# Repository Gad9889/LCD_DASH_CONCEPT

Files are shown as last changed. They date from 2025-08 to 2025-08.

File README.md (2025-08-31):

# Dash Concept – Design Summary (Rev 0.1)

A compact STM32H745-based dash concept for an LCD‑driven vehicle interface. This repository documents the hardware concept, interfaces, and bring‑up notes for the first spin (Rev 0.1).

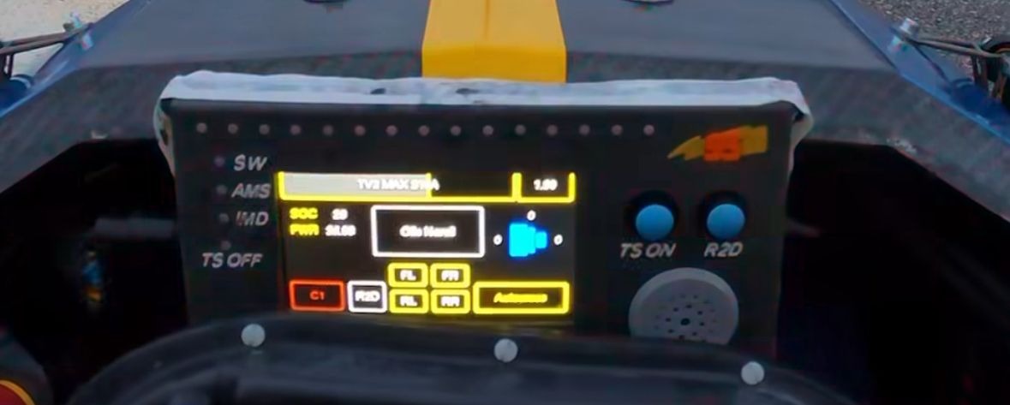
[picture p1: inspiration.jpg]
Inspiration – Chalmers Formula Student dashboard


> **Inspiration**: UI/UX styling reference from the Chalmers Formula Student team. The image is a visual reference, not a functional specification.

---

## Documents (in this repo)

Direct links with short descriptions:

- **Dash Concept Summary** → [Dash_Concept_Summary_Rev0_1.pdf](./Dash_Concept_Summary_Rev0_1.pdf) — condensed overview of the concept (Rev 0.1), interfaces, LCD details, RF notes, and expansion paths.
- **Schematics** → [Schematics.pdf](./Schematics.pdf) — electrical design: power (12 V → 3.3 V buck and decoupling), MCU pinout, FMC LCD connector, ST‑LINK/JTAG, CAN/USART, and RF (CC2500 with 26 MHz crystal and matching network).
- **Design Breakdown** → [Design Breakdown.pdf](./Design%20Breakdown.pdf) — manufacturing‑oriented summary: board dimensions, 4‑layer stackup with target impedances, layer previews (Top/Bottom/L1–L4), BOM snapshot, and drill table.
- **CubeMX Report** → [DashCubeMX.pdf](./DashCubeMX.pdf) — STM32CubeMX configuration: MCU selection and package, pin assignments (FMC NE3/A8, USART6, SPI1, FDCAN1), clock tree, and initial FMC timings.

---

## Highlights

- **Concept status**: Rev 0.1 (pre‑prototype)
- **MCU**: STM32H745ZITx (LQFP144), Cortex‑M7 + Cortex‑M4
- **Primary functions**: LCD over FMC, RF over SPI1 (CC2500), CAN‑FD, SWD/JTAG, UART console
- **Board**: 137 mm × 94 mm, 4‑layer FR‑4, target impedances 50 Ω SE / 90 Ω diff

## Hardware Overview

- **Power**: +12 V input → TPS62130 buck → +3.3 V. Local 100 nF decoupling per VDD plus bulk caps (e.g., 4.7 µF/10 µF/22 µF).
- **Clocks**: HSE bypass to PLL; targets M7 @ 480 MHz and M4 @ 240 MHz.

### Key Interfaces

| Interface | Details |
| --- | --- |
| **FMC (LCD)** | Bank1 **NE3** as chip‑select; **A8** used as D/C (register select). 16‑bit data bus **D0..D15**. Control **NOE=RD**, **NWE=WR**. |
| **USART6** | 115200 baud (TX PC6, RX PC7). |
| **SPI1** | NSS PA4, SCK PA5, MISO PA6, MOSI PA7 (to RF). |
| **FDCAN1** | FD mode (PB8 RX, PB9 TX). |
| **SWD/JTAG**  | ST‑LINK V3: SWDIO, SWCLK, JTDI, SWO, NRST. |

### LCD Screen Details — ER‑TFTM050‑5

| Parameter | Value |
| --- | --- |
| Diagonal size  | 5.0″ |
| Resolution | 800 × 480 (RGB) |
| Active area | 108.0 mm × 64.8 mm |
| Outline (PCB)  | 132.7 mm × 75.95 mm |
| Interface | 8080/6800 parallel, selectable 8/9/16/18/24‑bit; **SSD1963** controller |
| Supply options | VDD 3.3 V (J8 short) or 5.0 V (J8 open); logic VDDIO 3.3 V |
| Module current | ≈ 280 mA @ 5 V, up to ~450 mA @ 3.3 V |
| Brightness | 300 cd/m² (typ.) |
| Contrast | 500:1 (typ.) |
| Viewing angle  | L/R 75°, Up 75°, Down 60° (typ.) |
| Operating temp | −20 °C … +70 °C |

### LCD Connector (JP2 / CON1 highlights)

| Pin(s) | Signal | Notes |
| --- | --- | --- |
| 1, 40  | VSS | Ground |
| 2 | VDD | 3.3 V or 5 V (per module option) |
| 3 | /CS | Chip‑select — connect to **FMC NE3** |
| 4 | D/C | Data/Command — connect to **A8** |
| 5 | RD | 8080 read strobe — connect to **NOE**  |
| 6 | WR | 8080 write strobe — connect to **NWE** |
| 7 | RESET | Active‑low reset (recommended) |
| 8 | TE | Tearing effect (optional) |
| 9–32 | DB0–DB23 | Use **DB0–DB15** for 16‑bit mode |
| 39 | BL_ON | Backlight control (optional PWM) |

### RF Subsystem

- **Transceiver**: TI **CC2500** (2.4 GHz) on SPI1 with GDO0/GDO2 interrupts and a 26 MHz crystal.
- **Front‑end**: Minimal matching network and antenna port in Rev 0.1 (no PA/LNA/SAW). Future spins can add PA/LNA and alternative radios using spare I/O.

### FMC Timing (initial)

- Address setup: 15 cycles
- Data setup: 255 cycles
- Bus turn‑around: 15 cycles  
  _Tune per LCD controller timing requirements._

## Minimal Concept & Expansion Paths

Rev 0.1 targets power‑up, clocks, debug, FMC LCD, SPI RF, CAN, and UART console. Reserved pins/area allow:

- External storage (QSPI/SD), audio codec, backlight driver with PWM dimming
- Additional sensors and buttons/encoders
- Extended RF front‑end (PA/LNA) or radio swap

## References

- ST RM0399 — STM32H745/755/747/757 Reference Manual  
  https://www.st.com/resource/en/reference_manual/rm0399-stm32h745755-and-stm32h747757-advanced-armbased-32bit-mcus-stmicroelectronics.pdf
- EastRising ER‑TFTM050‑5 TFT LCD Datasheet  
  https://www.buydisplay.com/download/manual/ER-TFTM050-5_Datasheet.pdf

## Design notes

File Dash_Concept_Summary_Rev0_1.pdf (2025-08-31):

### Dash Concept - Design Summary (Rev 0.1)

# Dash Concept - Design Summary

Scope: this document summarizes the current concept board based on the STM32H745 microcontroller. Hardware status is Rev 0.1 (pre-prototype). It consolidates information from the CubeMX configuration and the schematics.

## Inspiration

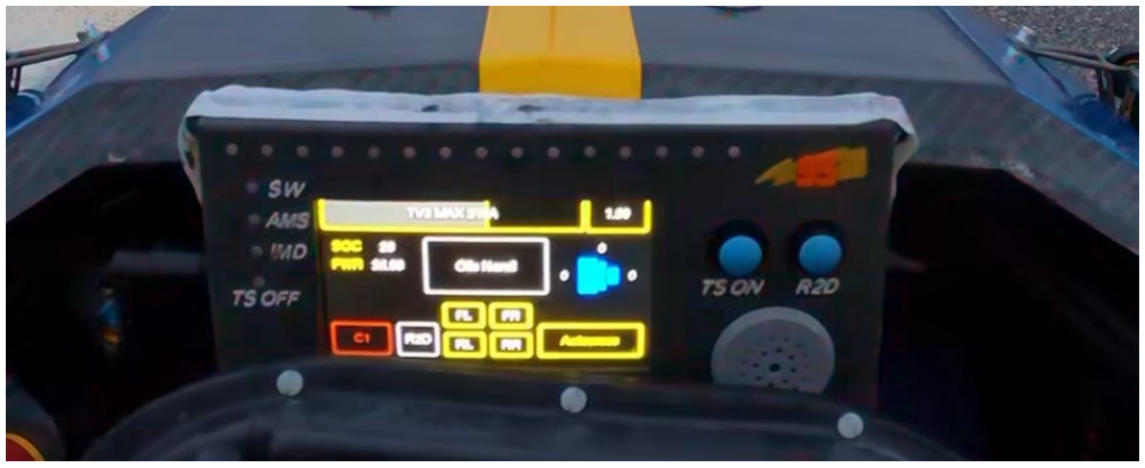
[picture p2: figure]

Dashboard visual inspiration: Chalmers Formula Student team. The image is used as a stylistic reference for UI layout and features, not as a functional specification.

## Board Overview

Form factor: 137 mm x 94 mm, thickness 1.6 mm, 4 layers (FR4). Target controlled impedances: 50 ohm single ended and 90 ohm differential per stackup. Primary functions: LCD via FMC, RF via SPI1, CAN FD via FDCAN1, debug via SWD/JTAG.

## MCU and Clocks

MCU: STM32H745ZITx (LQFP144), dual core Cortex-M7 and Cortex-M4. CubeMX configuration targets M7 at 480 MHz and M4 at 240 MHz using HSE bypass and PLLs.

## Power System

Input: +12 V. Main regulator: TPS62130 buck converter to +3.3 V. Local decoupling: 100 nF at each VDD/VSSA pin plus bulk values (for example 4.7 uF, 10 uF, 22 uF) as shown in the schematic.

## Key Interfaces

Interface | Details
FMC (LCD) | Bank1 NE3 as chip select. A8 used as D/C (register select). 16-bit data bus D0..D15. Control NOE=RD, NWE=WR.
USART6 | Async 115200 baud (TX on PC6, RX on PC7).
SPI1 | Master interface to RF transceiver (NSS PA4, SCK PA5, MISO PA6, MOSI PA7).
FDCAN1 | FD mode (PB8 RX, PB9 TX).
SWD/JTAG | ST-LINK V3: SWDIO, SWCLK, JTDI, SWO and NRST.

## RF Subsystem

2.4 GHz transceiver: CC2500 on SPI1 with GDO0/GDO2 interrupts and a 26 MHz crystal. Includes a compact matching network and antenna port. Rev 0.1 keeps the RF minimal for bring-up (no external PA/LNA or SAW). Future expansion can add PA/LNA front-end, on-board antenna options, or alternative radios using spare MCU I/O and board area.

## Initial FMC Timing (from CubeMX)

Address setup: 15 cycles; Data setup: 255 cycles; Bus turn around: 15 cycles. Adjust these values to meet the LCD controller timing.

## LCD Connector (ER-TFTM050-5, JP2/CON1 highlights)

Pin(s) | Signal | Notes
1,40 | VSS | Ground
2 | VDD | 3.3 V or 5 V (per module)
3 | /CS | Chip select (connect to FMC NE3)
4 | D/C | Data or Command (connect to A8)
5 | RD | 8080 read strobe (connect to NOE)
6 | WR | 8080 write strobe (connect to NWE)
7 | RESET | Active low, recommended
8 | TE | Optional tearing effect
9-32 | DB0-DB23 | Use DB0-DB15 for 16-bit mode
39 | BL_ON | Backlight control (optional PWM)

## LCD Screen Details (ER-TFTM050-5)

Parameter | Value
Diagonal size | 5.0 inch
Resolution | 800 x 480 (RGB)
Active area | 108.0 mm x 64.8 mm
Outline (PCB) | 132.7 mm x 75.95 mm
Interface | 8080/6800 parallel, selectable 8/9/16/18/24-bit; SSD1963 controller
Supply options | VDD 3.3 V (J8 short) or 5.0 V (J8 open); logic VDDIO 3.3 V
Module current (typ/max) | ~280 mA @5V, up to 450 mA @3.3V
Brightness (typ) | 300 cd/m²
Contrast (typ) | 500:1
Viewing angle (typ) | Left 75°, Right 75°, Up 75°, Down 60°
Operating temp | -20°C to +70°C

## Minimal Concept and Expansion Paths

Rev 0.1 focuses on the minimum viable hardware to validate power-up, clocks, debug, FMC LCD, SPI RF, CAN, and a UART console. The layout and spare pins leave room for future features such as external storage, audio codec, backlight driver with PWM dimming, additional sensors, and extended radio front-end.

## Files Provided

File | Description
Design Breakdown.pdf | Manufacturing-oriented summary: board dimensions, 4-layer stackup with target impedances, layer previews (Top/Bottom/L1–L4), BOM snapshot, and drill table.
Schematics.pdf | Electrical design: Power (12 V to 3.3 V buck and decoupling), I/O (MCU pinout, FMC LCD connector, ST-LINK/JTAG, CAN, USART), and RF (CC2500 with 26 MHz crystal, matching network, and antenna).
DashCubeMX.pdf | STM32CubeMX configuration report: MCU selection and package, pin assignments (FMC NE3/A8, USART6, SPI1, FDCAN1), clock tree, and initial FMC timings.

## References

MCU Reference Manual RM0399 (STM32H745/755/747/757): Open link (https://www.st.com/resource/en/reference_manual/rm0399-stm32h745755-and-stm32h747757-advanced-armbased-32bit-mcus-stmicroelectronics.pdf) (URL: https://www.st.com/resource/en/reference_manual/rm0399-stm32h745755-and-stm32h747757-advanced-armbased-32bit-mcus-stmicroelectronic s.pdf)

LCD Datasheet ER-TFTM050-5: Open link (https://www.buydisplay.com/download/manual/ER-TFTM050-5_Datasheet.pdf) (URL: https://www.buydisplay.com/download/manual/ER-TFTM050-5_Datasheet.pdf)

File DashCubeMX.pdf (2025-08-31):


31/08/2025

dash Project
Configuration Report

## 1. Description

### 1.1. Project

Project Name | dash
Board Name | custom
Generated with: | STM32CubeMX 6.14.0
Date | 08/31/2025

### 1.2. MCU

MCU Series | STM32H7
MCU Line | STM32H745/755
MCU name | STM32H745ZITx
MCU Package | LQFP144
MCU Pin number | 144

### 1.3. Core(s) information

Core(s) | ARM Cortex-M7 ARM Cortex-M4

## 2. Pinout Configuration

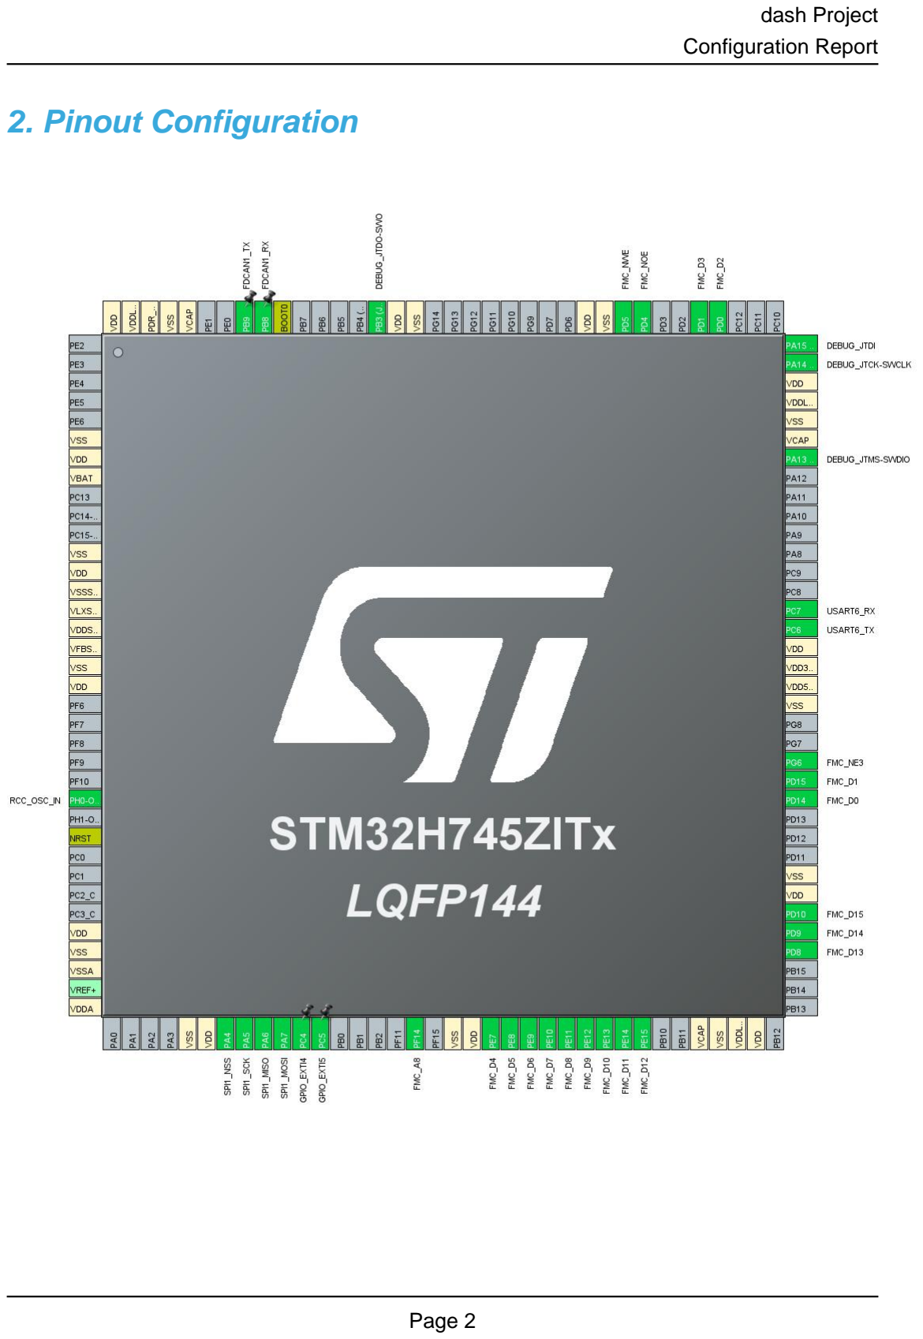
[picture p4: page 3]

## 3. Pins Configuration

Pin Number LQFP144 | Pin Name (function after reset) | Pin Type | Alternate Function(s) | Label
6 | VSS | Power
7 | VDD | Power
8 | VBAT | Power
12 | VSS | Power
13 | VDD | Power
14 | VSSSMPS | Power
15 | VLXSMPS | Power
16 | VDDSMPS | Power
17 | VFBSMPS | Power
18 | VSS | Power
19 | VDD | Power
25 | PH0-OSC_IN (PH0) | I/O | RCC_OSC_IN
27 | NRST | Reset
32 | VDD | Power
33 | VSS | Power
34 | VSSA | Power
36 | VDDA | Power
41 | VSS | Power
42 | VDD | Power
43 | PA4 | I/O | SPI1_NSS
44 | PA5 | I/O | SPI1_SCK
45 | PA6 | I/O | SPI1_MISO
46 | PA7 | I/O | SPI1_MOSI
47 | PC4 | I/O | GPIO_EXTI4
48 | PC5 | I/O | GPIO_EXTI5
53 | PF14 | I/O | FMC_A8
55 | VSS | Power
56 | VDD | Power
57 | PE7 | I/O | FMC_D4
58 | PE8 | I/O | FMC_D5
59 | PE9 | I/O | FMC_D6
60 | PE10 | I/O | FMC_D7
61 | PE11 | I/O | FMC_D8
62 | PE12 | I/O | FMC_D9
63 | PE13 | I/O | FMC_D10
64 | PE14 | I/O | FMC_D11

Pin Number LQFP144 | Pin Name (function after reset) | Pin Type | Alternate Function(s) | Label
65 | PE15 | I/O | FMC_D12
68 | VCAP | Power
69 | VSS | Power
70 | VDDLDO | Power
71 | VDD | Power
76 | PD8 | I/O | FMC_D13
77 | PD9 | I/O | FMC_D14
78 | PD10 | I/O | FMC_D15
79 | VDD | Power
80 | VSS | Power
84 | PD14 | I/O | FMC_D0
85 | PD15 | I/O | FMC_D1
86 | PG6 | I/O | FMC_NE3
89 | VSS | Power
90 | VDD50_USB | Power
91 | VDD33_USB | Power
92 | VDD | Power
93 | PC6 | I/O | USART6_TX
94 | PC7 | I/O | USART6_RX
102 | PA13 (JTMS/SWDIO) | I/O | DEBUG_JTMS-SWDIO
103 | VCAP | Power
104 | VSS | Power
105 | VDDLDO | Power
106 | VDD | Power
107 | PA14 (JTCK/SWCLK) | I/O | DEBUG_JTCK-SWCLK
108 | PA15 (JTDI) | I/O | DEBUG_JTDI
112 | PD0 | I/O | FMC_D2
113 | PD1 | I/O | FMC_D3
116 | PD4 | I/O | FMC_NOE
117 | PD5 | I/O | FMC_NWE
118 | VSS | Power
119 | VDD | Power
128 | VSS | Power
129 | VDD | Power
130 | PB3 (JTDO/TRACESWO) | I/O | DEBUG_JTDO-SWO
135 | BOOT0 | Boot
136 | PB8 | I/O | FDCAN1_RX
137 | PB9 | I/O | FDCAN1_TX
140 | VCAP | Power

Pin Number LQFP144 | Pin Name (function after reset) | Pin Type | Alternate Function(s) | Label
141 | VSS | Power
142 | PDR_ON | Power
143 | VDDLDO | Power
144 | VDD | Power

## 4. Clock Tree Configuration

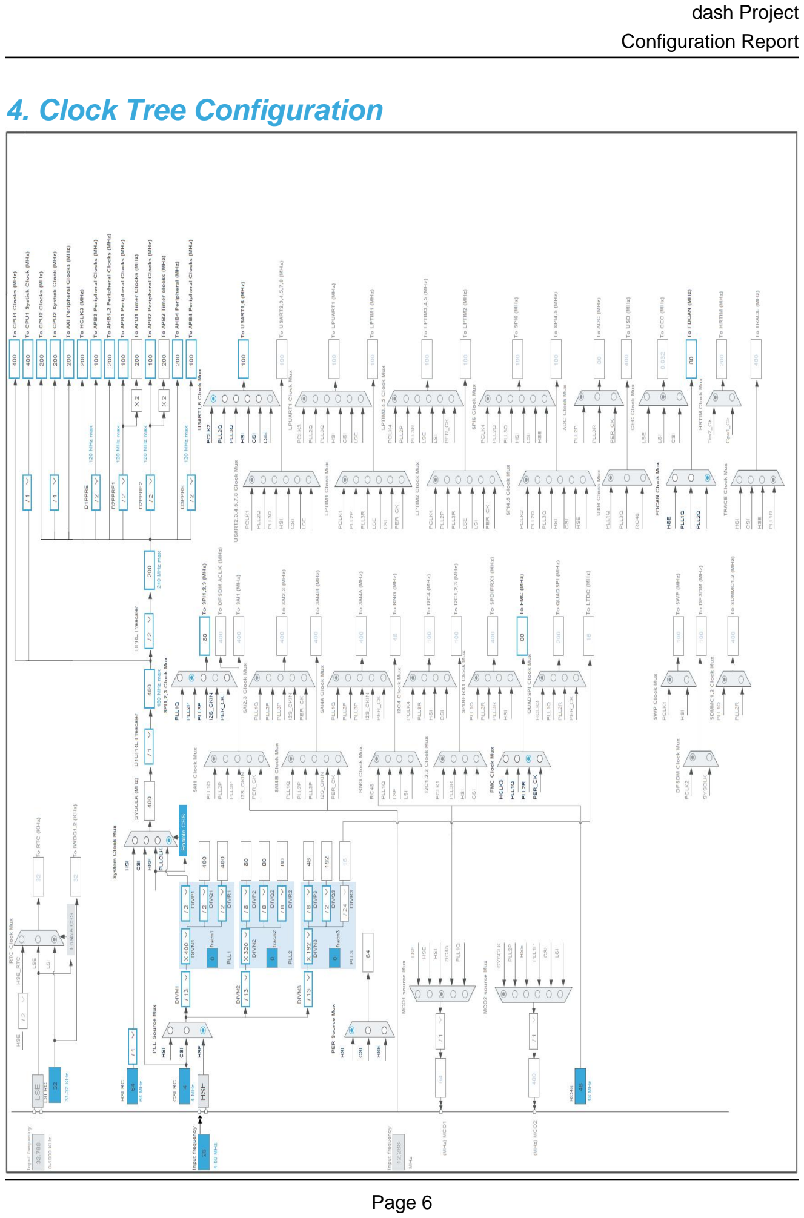
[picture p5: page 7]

## 1. Power Consumption Calculator report

### 1.1. Microcontroller Selection

Series | STM32H7
Line | STM32H745/755
MCU | STM32H745ZITx
Datasheet | DS12923_Rev1

### 1.2. Parameter Selection

Temperature | 25
Vdd | 3.0

### 1.3. Battery Selection

Battery | Li-SOCL2(DD36000)
Capacity | 36000.0 mAh
Self Discharge | 0.08 %/month
Nominal Voltage | 3.6 V
Max Cont Current | 450.0 mA
Max Pulse Current | 1000.0 mA
Cells in series | 1
Cells in parallel | 1

### 1.4. Sequence

Step | Step1 | Step2
Mode | RUN | STOP
Vdd | 3.0 | 3.0
Voltage Source | Battery | Battery
Range | VOS0: Scale0 | SVOS5: System-Scale5
D1 Mode | DRUN/CRUN | DSTANDBY
D2 Mode | DRUN/CRUN | DSTANDBY
D3 Mode | DRUN | DSTOP
Fetch Type | CM7: ITCM/Cache / CM4: FLASH_B/ART | CM7: NA / CM4: NA
CM7 Frequency | 480 MHz | 0 Hz
Clock Configuration | HSE BYP PLL ALL_IPs_ON | LSE Flash-ON
CM4 Frequency | 240 MHz | 0 Hz
Clock Source Frequency | 25 MHz | 0 Hz
Peripherals
Additional Cons. | 0 mA | 0 mA
Average Current | 247 mA | 145 µA
Duration | 0.1 ms | 0.9 ms
DMIPS | 1027.0 | 0.0
Category | In DS Table | In DS Table

### 1.5. Results

Sequence Time | 1 ms | Average Current | 24.83 mA
Battery Life | 1 month, 29 days, 21 hours | Average DMIPS | 1027.2001 DMIPS

### 1.6. Chart

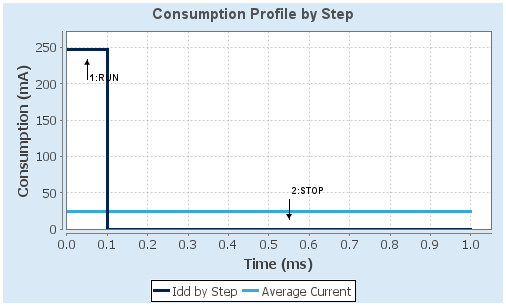
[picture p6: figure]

## 2. Software Project

### 2.1. Project Settings

Name | Value
Project Name | dash
Project Folder | C:\Users\ramga\Desktop\projects\dash
Toolchain / IDE | EWARM V8.50
Firmware Package Name and Version | STM32Cube FW_H7 V1.12.1
Application Structure | Advanced
Generate Under Root | No
Do not generate the main() | No
Minimum Heap Size | M4-0x200
Minimum Stack Size | M4-0x400

### 2.2. Code Generation Settings

Name | Value
STM32Cube MCU packages and embedded software | Copy all used libraries into the project folder
Generate peripheral initialization as a pair of '.c/.h' files | No
Backup previously generated files when re-generating | No
Keep User Code when re-generating | Yes
Delete previously generated files when not re-generated | Yes
Set all free pins as analog (to optimize the power consumption) | No
Enable Full Assert | No

### 2.3. Advanced Settings - Generated Function Calls ARM Cortex-M7

Rank | Function Name | Peripheral Instance Name
1 | SystemClock_Config | RCC
2 | MX_GPIO_Init | GPIO
3 | MX_CRC_Init | CRC
4 | MX_DMA2D_Init | DMA2D
5 | MX_FMC_Init | FMC

### 2.4. Advanced Settings - Generated Function Calls ARM Cortex-M4

Rank | Function Name | Peripheral Instance Name
1 | MX_GPIO_Init | GPIO

Rank | Function Name | Peripheral Instance Name
2 | MX_FDCAN1_Init | FDCAN1
3 | MX_SPI1_Init | SPI1
4 | MX_USART6_UART_Init | USART6

## 3. Peripherals and Middlewares Configuration

### 3.1. CORTEX_M4

3.1.1. Parameter Settings:

Core(s) Settings:

Context(s): | Cortex-M4
Initialized Context: | Cortex-M4
Power Domain: | D2

Cortex Memory Protection Unit Control Settings:
MPU Control Mode | Background Region Privileged accesses only + MPU Disabled during hard fault, NMI and FAULTMASK handlers *

Cortex Memory Protection Unit Region 0 Settings:

MPU Region | Disabled
Cortex Memory Protection Unit Region 1 Settings:
MPU Region | Disabled
Cortex Memory Protection Unit Region 2 Settings:
MPU Region | Disabled
Cortex Memory Protection Unit Region 3 Settings:
MPU Region | Disabled
Cortex Memory Protection Unit Region 4 Settings:
MPU Region | Disabled
Cortex Memory Protection Unit Region 5 Settings:
MPU Region | Disabled
Cortex Memory Protection Unit Region 6 Settings:
MPU Region | Disabled
Cortex Memory Protection Unit Region 7 Settings:
MPU Region | Disabled

### 3.2. CORTEX_M7

3.2.1. Parameter Settings:

Core(s) Settings:

Context(s): | Cortex-M7
Initialized Context: | Cortex-M7
Power Domain: | D1

Speculation default mode Settings:

Speculation default mode | Enabled *
Cortex Interface Settings:
CPU ICache | Disabled
CPU DCache | Disabled
Cortex Memory Protection Unit Control Settings:
MPU Control Mode | Background Region Privileged accesses only + MPU Disabled during hard fault, NMI and FAULTMASK handlers

Cortex Memory Protection Unit Region 0 Settings:

MPU Region | Enabled
MPU Region Base Address | 0x0 *
MPU Region Size | 4GB
MPU SubRegion Disable | 0x87 *
MPU TEX field level | level 0
MPU Access Permission | ALL ACCESS NOT PERMITTED
MPU Instruction Access | DISABLE
MPU Shareability Permission | ENABLE
MPU Cacheable Permission | DISABLE
MPU Bufferable Permission | DISABLE
Cortex Memory Protection Unit Region 1 Settings:
MPU Region | Disabled
Cortex Memory Protection Unit Region 2 Settings:
MPU Region | Disabled
Cortex Memory Protection Unit Region 3 Settings:
MPU Region | Disabled
Cortex Memory Protection Unit Region 4 Settings:
MPU Region | Disabled
Cortex Memory Protection Unit Region 5 Settings:
MPU Region | Disabled
Cortex Memory Protection Unit Region 6 Settings:
MPU Region | Disabled
Cortex Memory Protection Unit Region 7 Settings:
MPU Region | Disabled
Cortex Memory Protection Unit Region 8 Settings:
MPU Region | Disabled
Cortex Memory Protection Unit Region 9 Settings:
MPU Region | Disabled
Cortex Memory Protection Unit Region 10 Settings:
MPU Region | Disabled
Cortex Memory Protection Unit Region 11 Settings:

MPU Region | Disabled
Cortex Memory Protection Unit Region 12 Settings:
MPU Region | Disabled
Cortex Memory Protection Unit Region 13 Settings:
MPU Region | Disabled
Cortex Memory Protection Unit Region 14 Settings:
MPU Region | Disabled
Cortex Memory Protection Unit Region 15 Settings:
MPU Region | Disabled

### 3.3. CRC

mode: Activated
3.3.1. Parameter Settings:

Core(s) Settings:

Context(s): | Cortex-M7
Initialized Context: | Cortex-M7
Power Domain: | D3

Basic Parameters:

Default Polynomial State | Enable
Default Init Value State | Enable
Advanced Parameters:
Input Data Inversion Mode | None
Output Data Inversion Mode | Disable
Input Data Format | Bytes

### 3.4. DEBUG

Debug: JTAG (4 pins)
3.4.1. Core(s) Settings:
Context(s): | Cortex-M4
Initialized Context: | Cortex-M4

Power Domain:

### 3.5. DMA2D

mode: Activated
3.5.1. Parameter Settings:

Core(s) Settings:

Context(s): | Cortex-M7
Initialized Context: | Cortex-M7
Power Domain: | D1

Basic Parameters:

Transfer Mode | Memory to Memory
Color Mode | ARGB8888
Output Offset | 0
Foreground layer Configuration:
DMA2D Input Color Mode | ARGB8888
DMA2D ALPHA MODE | No modification of the alpha channel value
Input Alpha | 0
Input Offset | 0
DMA2D ALPHA Inversion | Regular Alpha
DMA2D Red and Blue swap | Regular mode (RGB or ARGB)
DMA2D Chroma Sub-Sampling Mode | No chroma sub-sampling 4:4:4

### 3.6. FDCAN1

mode: Activated
3.6.1. Parameter Settings:

Core(s) Settings:

Context(s): | Cortex-M4
Initialized Context: | Cortex-M4
Power Domain: | D2

Basic Parameters:
Frame Format | FD mode without BitRate Switching *
Mode | Normal mode
Auto Retransmission | Disable
Transmit Pause | Disable
Protocol Exception | Disable

Nominal Sync Jump Width | 1
Data Prescaler | 1
Data Sync Jump Width | 1
Data Time Seg1 | 1
Data Time Seg2 | 1
Message Ram Offset | 0
Std Filters Nbr | 0
Ext Filters Nbr | 0
Rx Fifo0 Elmts Nbr | 0
Rx Fifo0 Elmt Size | 8 bytes data field
Rx Fifo1 Elmts Nbr | 0
Rx Fifo1 Elmt Size | 8 bytes data field
Rx Buffers Nbr | 0
Rx Buffer Size | 8 bytes data field
Tx Events Nbr | 0
Tx Buffers Nbr | 0
Tx Fifo Queue Elmts Nbr | 0
Tx Fifo Queue Mode | FIFO mode
Tx Elmt Size | 8 bytes data field
Clock Calibration Unit:
Clock Calibration | Disable
Bit Timings Parameters:
Nominal Prescaler | 16
Nominal Time Quantum | 200.0 *
Nominal Time Seg1 | 1
Nominal Time Seg2 | 1
Nominal Time for one Bit | 600 *
Nominal Baud Rate | 1666666 *

### 3.7. FMC

NOR Flash/PSRAM/SRAM/ROM/LCD 1 Chip Select: NE3
Memory type: LCD Interface
LCD Register Select: A8
Data: 16 bits
3.7.1. NOR/PSRAM 1:

Core(s) Settings:

Context(s):

| Cortex-M7
Initialized Context: | Cortex-M7
Power Domain: | D1

NOR/PSRAM control:

Memory type | LCD Interface
Bank | Bank 1 NOR/PSRAM 3
Write operation | Enabled
Write FIFO | Enabled
Extended mode | Disabled
NOR/PSRAM timing:
Address setup time in FMC clock cycles | 15
Data setup time in FMC clock cycles | 255
Bus turn around time in FMC clock cycles | 15
3.7.2. Bank Mapping:

Core(s) Settings:

Context(s): | Cortex-M7
Initialized Context: | Cortex-M7
Power Domain: | D1

Mapping parameters:

FMC bank mapping | Default mapping

### 3.8. RCC

High Speed Clock (HSE): BYPASS Clock Source
3.8.1. Parameter Settings:

Core(s) Settings:

Context(s): | Cortex-M7 Cortex-M4
Initialized Context: | Cortex-M7
Power Domain: | D3

Power Parameters:
SupplySource | PWR_LDO_SUPPLY *
Power Regulator Voltage Scale | Power Regulator Voltage Scale 1

RCC Parameters:

TIM Prescaler Selection | Disabled
HSE Startup Timout Value (ms) | 100
LSE Startup Timout Value (ms) | 5000
CSI Calibration Value | 32
HSI Calibration Value | 64
System Parameters:
VDD voltage (V) | 3.3
Flash Latency(WS) | 2 WS (3 CPU cycle)
Product revision | rev.V
PLL range Parameters:
PLL1 clock Input range | Between 2 and 4 MHz
PLL2 input frequency range | Between 2 and 4 MHz
PLL1 clock Output range | Wide VCO range
PLL2 clock Output range | Wide VCO range

### 3.9. SPI1

Mode: Full-Duplex Master
Hardware NSS Signal: Hardware NSS Input Signal
3.9.1. Parameter Settings:

Core(s) Settings:

Context(s): | Cortex-M4
Initialized Context: | Cortex-M4
Power Domain: | D2

Basic Parameters:

Frame Format | Motorola
Data Size | 8 Bits *
First Bit | MSB First
Clock Parameters:
Prescaler (for Baud Rate) | 16 *
Baud Rate | 5.0 MBits/s *
Clock Polarity (CPOL) | Low
Clock Phase (CPHA) | 1 Edge
Advanced Parameters:
CRC Calculation | Disabled
NSSP Mode | Enabled

NSS Signal Type | Input Hardware
Fifo Threshold | Fifo Threshold 01 Data
Tx Crc Initialization Pattern | All Zero Pattern
Rx Crc Initialization Pattern | All Zero Pattern
Nss Polarity | Nss Polarity Low
Master Ss Idleness | 00 Cycle
Master Inter Data Idleness | 00 Cycle
Master Receiver Auto Susp | Disable
Master Keep Io State | Master Keep Io State Disable
IO Swap | Disabled

### 3.10. SYS_M4

Timebase Source: SysTick
3.10.1. Core(s) Settings:
Context(s): | Cortex-M4
Initialized Context: | Cortex-M4

Power Domain:

### 3.11. SYS

Timebase Source: SysTick
3.11.1. Core(s) Settings:
Context(s): | Cortex-M7
Initialized Context: | Cortex-M7

Power Domain:

### 3.12. USART6

Mode: Asynchronous
3.12.1. Parameter Settings:

Core(s) Settings:

Context(s): | Cortex-M4
Initialized Context: | Cortex-M4

Power Domain: | D2

Basic Parameters:

Baud Rate | 115200
Word Length | 8 Bits (including Parity)
Parity | None
Stop Bits | 1
Advanced Parameters:
Data Direction | Receive and Transmit
Over Sampling | 16 Samples
Single Sample | Disable
ClockPrescaler | 1
Fifo Mode | Disable
Txfifo Threshold | 1 eighth full configuration
Rxfifo Threshold | 1 eighth full configuration
Advanced Features:
Auto Baudrate | Disable
TX Pin Active Level Inversion | Disable
RX Pin Active Level Inversion | Disable
Data Inversion | Disable
TX and RX Pins Swapping | Disable
Overrun | Enable
DMA on RX Error | Enable
MSB First | Disable

* User modified value

## 4. System Configuration

### 4.1. GPIO configuration

IP | Pin | Signal | GPIO mode | GPIO pull/up pull down | Max Speed | User Label | Context | Power Domain
DEBUG | PA13 (JTMS/S WDIO) | DEBUG_JTM S-SWDIO | n/a | n/a | n/a | | Cortex-M4 | Cortex-M4
| PA14 (JTCK/S WCLK) | DEBUG_JTC K-SWCLK | n/a | n/a | n/a | | Cortex-M4 | Cortex-M4
| PA15 (JTDI) | DEBUG_JTD I | n/a | n/a | n/a | | Cortex-M4 | Cortex-M4
| PB3 (JTDO/TR ACESWO | DEBUG_JTD O-SWO | n/a | n/a | n/a | | Cortex-M4 | Cortex-M4
FDCAN1 | PB8 | FDCAN1_RX | Alternate Function Push Pull | No pull-up and no pull-down | Low | | Cortex-M4 | D2
| PB9 | FDCAN1_TX | Alternate Function Push Pull | No pull-up and no pull-down | Low | | Cortex-M4 | D2
| | | Push Pull | No pull-up and no pull-down | Very High | | Cortex-M7 | D1
| PE7 | FMC_D4 | Alternate Function Push Pull | No pull-up and no pull-down | Very High | | Cortex-M7 | D1
| PE8 | FMC_D5 | Alternate Function Push Pull | No pull-up and no pull-down | Very High | | Cortex-M7 | D1
| PE9 | FMC_D6 | Alternate Function Push Pull | No pull-up and no pull-down | Very High | | Cortex-M7 | D1
| PE10 | FMC_D7 | Alternate Function Push Pull | No pull-up and no pull-down | Very High | | Cortex-M7 | D1
| PE11 | FMC_D8 | Alternate Function Push Pull | No pull-up and no pull-down | Very High | | Cortex-M7 | D1
| PE12 | FMC_D9 | Alternate Function Push Pull | No pull-up and no pull-down | Very High | | Cortex-M7 | D1
| PE13 | FMC_D10 | Alternate Function Push Pull | No pull-up and no pull-down | Very High | | Cortex-M7 | D1
| PE14 | FMC_D11 | Alternate Function Push Pull | No pull-up and no pull-down | Very High | | Cortex-M7 | D1
| PE15 | FMC_D12 | Alternate Function Push Pull | No pull-up and no pull-down | Very High | | Cortex-M7 | D1
| PD8 | FMC_D13 | Alternate Function Push Pull | No pull-up and no pull-down | Very High | | Cortex-M7 | D1
| PD9 | FMC_D14 | Alternate Function Push Pull | No pull-up and no pull-down | Very High | | Cortex-M7 | D1
| PD10 | FMC_D15 | Alternate Function Push Pull | No pull-up and no pull-down | Very High | | Cortex-M7 | D1
FMC | PF14 | FMC_A8 | Alternate Function

IP | Pin | Signal | GPIO mode | GPIO pull/up pull down | Max Speed | User Label | Context | Power Domain
| PD14 | FMC_D0 | Alternate Function Push Pull | No pull-up and no pull-down | Very High | | Cortex-M7 | D1
| PD15 | FMC_D1 | Alternate Function Push Pull | No pull-up and no pull-down | Very High | | Cortex-M7 | D1
| PG6 | FMC_NE3 | Alternate Function Push Pull | No pull-up and no pull-down | Very High | | Cortex-M7 | D1
| PD0 | FMC_D2 | Alternate Function Push Pull | No pull-up and no pull-down | Very High | | Cortex-M7 | D1
| PD1 | FMC_D3 | Alternate Function Push Pull | No pull-up and no pull-down | Very High | | Cortex-M7 | D1
| PD4 | FMC_NOE | Alternate Function Push Pull | No pull-up and no pull-down | Very High | | Cortex-M7 | D1
| PD5 | FMC_NWE | Alternate Function Push Pull | No pull-up and no pull-down | Very High | | Cortex-M7 | D1
RCC | PH0-OSC_IN (PH0) | RCC_OSC_I N | n/a | n/a | n/a | | Cortex-M7* Cortex-M4 | D3
SPI1 | PA4 | SPI1_NSS | Alternate Function Push Pull | No pull-up and no pull-down | Low | | Cortex-M4 | D2
| PA5 | SPI1_SCK | Alternate Function Push Pull | No pull-up and no pull-down | Low | | Cortex-M4 | D2
| PA6 | SPI1_MISO | Alternate Function Push Pull | No pull-up and no pull-down | Low | | Cortex-M4 | D2
| PA7 | SPI1_MOSI | Alternate Function Push Pull | No pull-up and no pull-down | Low | | Cortex-M4 | D2
USART6 | PC6 | USART6_TX | Alternate Function Push Pull | No pull-up and no pull-down | Low | | Cortex-M4 | D2
| PC7 | USART6_RX | Alternate Function Push Pull | No pull-up and no pull-down | Low | | Cortex-M4 | D2
GPIO | PC4 | GPIO_EXTI4 | External Interrupt Mode with Rising edge trigger detection | No pull-up and no pull-down | n/a | | Cortex-M7* Cortex-M4 | Cortex-M7* Cortex-M4
| PC5 | GPIO_EXTI5 | External Interrupt Mode with Rising edge trigger detection | No pull-up and no pull-down | n/a | | Cortex-M7* Cortex-M4 | Cortex-M7* Cortex-M4

* Initialized context

### 4.2. DMA configuration

nothing configured in DMA service

### 4.3. BDMA configuration

nothing configured in DMA service

### 4.4. MDMA configuration

nothing configured in DMA service

### 4.5. NVIC configuration

4.5.1. NVIC1
Interrupt Table | Enable | Preenmption Priority | SubPriority
Non maskable interrupt | true | 0 | 0
Hard fault interrupt | true | 0 | 0
Memory management fault | true | 0 | 0
Pre-fetch fault, memory access fault | true | 0 | 0
Undefined instruction or illegal state | true | 0 | 0
System service call via SWI instruction | true | 0 | 0
Debug monitor | true | 0 | 0
Pendable request for system service | true | 0 | 0
System tick timer | true | 15 | 0
PVD and AVD interrupts through EXTI line 16 | | unused
Flash global interrupt | | unused
RCC global interrupt | | unused
EXTI line4 interrupt | | unused
EXTI line[9:5] interrupts | | unused
CM4 send event interrupt for CM7 | | unused
FPU global interrupt | | unused
DMA2D global interrupt | | unused
HSEM1 global interrupt | | unused
Hold core interrupt | | unused
4.5.2. NVIC1 Code generation

Enabled interrupt Table Select for init
sequence ordering
| | Generate IRQ
| | handler | Call HAL handler
Non maskable interrupt | false | true | false
Hard fault interrupt | false | true | false
Memory management fault | false | true | false
Pre-fetch fault, memory access fault | false | true | false
Undefined instruction or illegal state | false | true | false
System service call via SWI instruction | false | true | false
Debug monitor | false | true | false
Pendable request for system service | false | true | false
System tick timer | false | true | true
4.5.3. NVIC2
Interrupt Table | Enable | Preenmption Priority | SubPriority
Non maskable interrupt | true | 0 | 0

Interrupt Table | Enable | Preenmption Priority | SubPriority
Hard fault interrupt | true | 0 | 0
Memory management fault | true | 0 | 0
Pre-fetch fault, memory access fault | true | 0 | 0
Undefined instruction or illegal state | true | 0 | 0
System service call via SWI instruction | true | 0 | 0
Debug monitor | true | 0 | 0
Pendable request for system service | true | 0 | 0
System tick timer | true | 15 | 0
PVD and AVD interrupts through EXTI line 16 | unused
Flash global interrupt | unused
EXTI line4 interrupt | unused
FDCAN1 interrupt 0 | unused
FDCAN1 interrupt 1 | unused
EXTI line[9:5] interrupts | unused
SPI1 global interrupt | unused
FDCAN calibration unit interrupt | unused
CM7 send event interrupt for CM4 | unused
USART6 global interrupt | unused
FPU global interrupt | unused
HSEM2 global interrupt | unused
Hold core interrupt | unused
4.5.4. NVIC2 Code generation
Enabled interrupt Table | Select for init sequence ordering | Generate IRQ handler | Call HAL handler
Non maskable interrupt | false | true | false
Hard fault interrupt | false | true | false
Memory management fault | false | true | false
Pre-fetch fault, memory access fault | false | true | false
Undefined instruction or illegal state | false | true | false
System service call via SWI instruction | false | true | false
Debug monitor | false | true | false
Pendable request for system service | false | true | false
System tick timer | false | true | true

* User modified value

## 5. System Views

5.1. Category view
5.1.1. Current

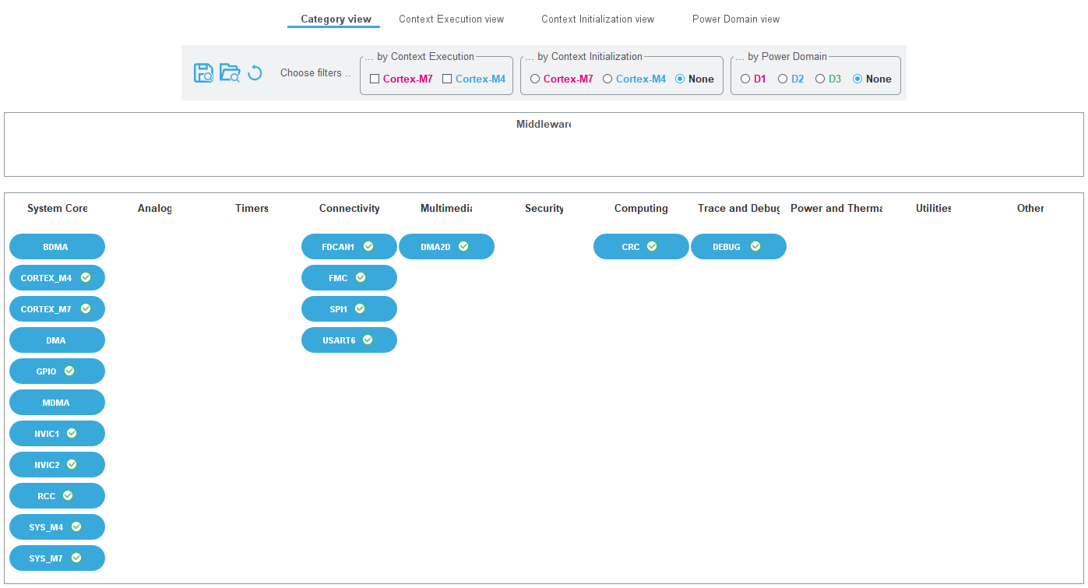
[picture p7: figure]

5.1.2. Without filters

5.2. Context Execution view

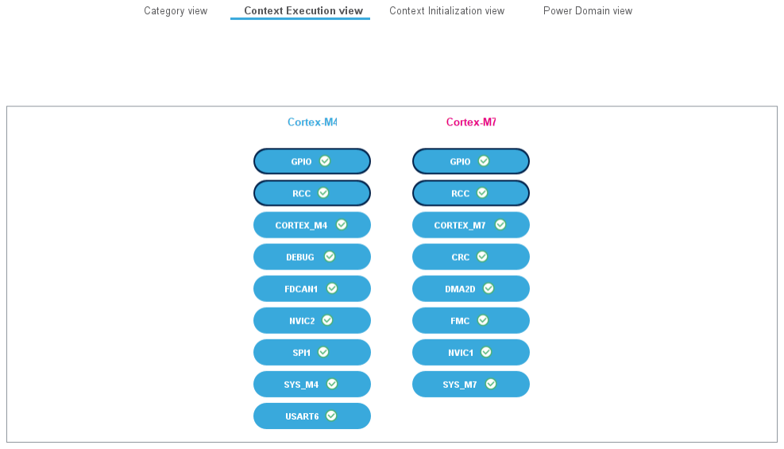
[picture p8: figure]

5.3. Context Initialization view

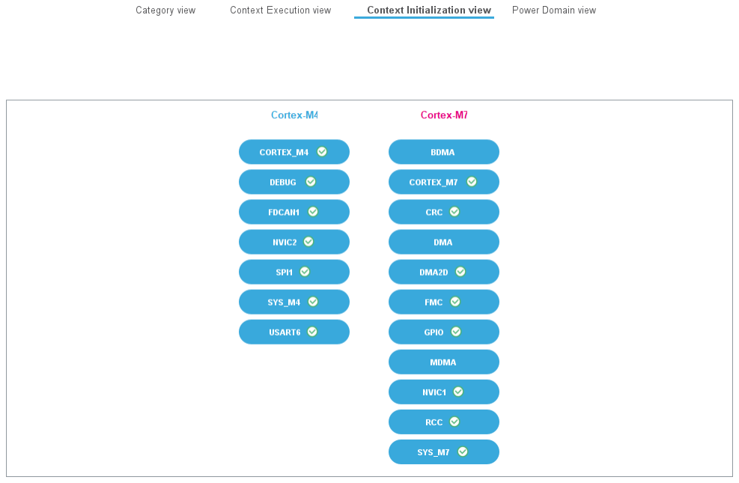
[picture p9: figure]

5.4. Power Domain view

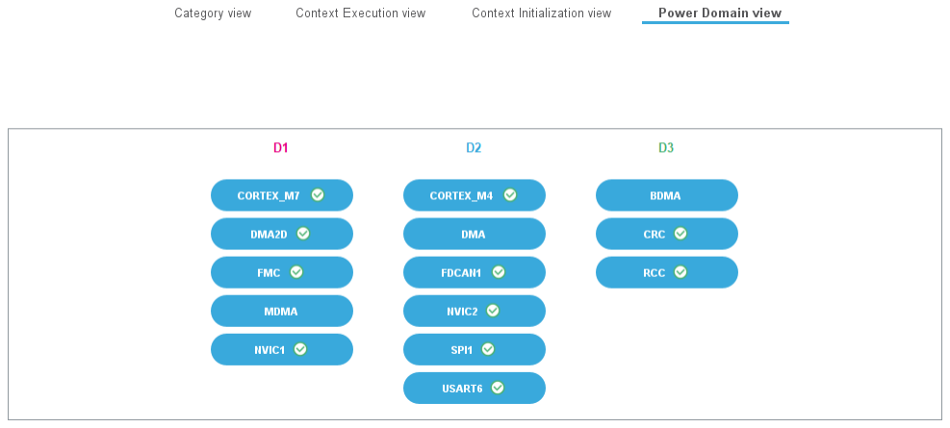
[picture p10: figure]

## 6. Docs & Resources

Type | Link
BSDL files | https://www.st.com/resource/en/bsdl_model/stm32h7_bsdl.zip
IBIS models | https://www.st.com/resource/en/ibis_model/stm32h7_ibis.zip
System View Description | https://www.st.com/resource/en/svd/stm32h7-svd.zip
Presentations | https://www.st.com/resource/en/product_presentation/microcontrollers_stm32h7_series_product_overview.pdf
Presentations | https://www.st.com/resource/en/product_presentation/stm32-stm8_embedded_software_solutions.pdf
Presentations | https://www.st.com/resource/en/product_presentation/stm32_eval-tools_portfolio.pdf
Presentations | https://www.st.com/resource/en/product_presentation/stm32_stm8_functi onal-safety-packages.pdf
Presentations | https://www.st.com/resource/en/product_presentation/stm32-stm8_software_development_tools.pdf
Presentations | https://www.st.com/resource/en/product_presentation/microcontrollers-stm32-family-overview.pdf
Presentations | https://www.st.com/resource/en/product_presentation/microcontrollers-stm32h7rs-lines-overview.pdf
Brochures | https://www.st.com/resource/en/brochure/brstm32h7.pdf
Flyers | https://www.st.com/resource/en/flyer/flstm32nucleo.pdf
Flyers | https://www.st.com/resource/en/flyer/flstm32trust.pdf
Flyers | https://www.st.com/resource/en/flyer/flstm32h7rs.pdf
Security Bulletin | https://www.st.com/resource/en/technical_note/tn1489-security-bulletin-tn1489stpsirt-physical-attacks-on-stm32-and-stm32cube-firmware-stmicroelectronics.pdf
Security Bulletin | https://www.st.com/resource/en/security_bulletin/sb0023-eucleak-protection-statement-for-stmicroelectronics-certified-products-stmicroelectronics.pdf
Application Notes | https://www.st.com/resource/en/application_note/an1709-emc-design-

| guide-for-stm8-stm32-and-legacy-mcus-stmicroelectronics.pdf
Application Notes | https://www.st.com/resource/en/application_note/an2606-stm32-microcontroller-system-memory-boot-mode-stmicroelectronics.pdf
Application Notes | https://www.st.com/resource/en/application_note/an3126-audio-and-waveform-generation-using-the-dac-in-stm32-products-stmicroelectronics.pdf
Application Notes | https://www.st.com/resource/en/application_note/an3155-usart-protocol-used-in-the-stm32-bootloader-stmicroelectronics.pdf
Application Notes | https://www.st.com/resource/en/application_note/an3156-usb-dfu-protocol-used-in-the-stm32-bootloader-stmicroelectronics.pdf
Application Notes | https://www.st.com/resource/en/application_note/an4221-i2c-protocol-used-in-the-stm32-bootloader-stmicroelectronics.pdf
Application Notes | https://www.st.com/resource/en/application_note/an4286-spi-protocol-used-in-the-stm32-bootloader-stmicroelectronics.pdf
Application Notes | https://www.st.com/resource/en/application_note/an4539-hrtim-cookbook-stmicroelectronics.pdf
Application Notes | https://www.st.com/resource/en/application_note/an4655-virtually-increasing-the-number-of-serial-communication-peripherals-in-stm32-applications-stmicroelectronics.p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
Application Notes | https://www.st.com/resource/en/application_note/an4750-handling-of-soft-errors-in-stm32-applications-stmicroelectronics.pdf
Application Notes | https://www.st.com/resource/en/application_note/an4776-generalpurpose-timer-cookbook-for-stm32-microcontrollers-stmicroelectronics.pdf
Application Notes | https://www.st.com/resource/en/application_note/an4803-highspeed-si-simulations-using-ibis-and-boardlevel-simulations-using-hyperlynx-si-on-stm32-mcus-and-mpus-stmic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
Application Notes | https://www.st.com/resource/en/application_note/an4839-level-1-cache-on-stm32f7-series-and-stm32h7-series-stmicroelectronics.pdf
Application Notes | https://www.st.com/resource/en/application_note/an4989-stm32-microcontroller-debug-toolbox-stmicroelectronics.pdf
Application Notes | https://www.st.com/resource/en/application_note/an4990-getting-started-with-sigmadelta-digital-interface-on-applicable-stm32-microcontrollers-stmicroelectronics.pdf

Application Notes | https://www.st.com/resource/en/application_note/an5027-interfacing-pdm-digital-microphones-using-stm32-mcus-and-mpus-stmicroelectronics.pdf
Application Notes | https://www.st.com/resource/en/application_note/an5033-stm32cube-mcu-package-examples-for-stm32h7-series-stmicroelectronics.pdf
Application Notes | https://www.st.com/resource/en/application_note/an5073-receiving-spdif-audio-stream-with-the-stm32f4f7h7-series-stmicroelectronics.pdf
Application Notes | https://www.st.com/resource/en/application_note/an5286-stm32h7x5x7-dualcore-microcontroller-debugging-stmicroelectronics.pdf
Application Notes | https://www.st.com/resource/en/application_note/an5354-getting-started-with-the-stm32h7-series-mcu-16bit-adc-stmicroelectronics.pdf
Application Notes | https://www.st.com/resource/en/application_note/an5557-stm32h745755-and-stm32h747757-lines-dualcore-architecture-stmicroelectronics.pdf
Application Notes | https://www.st.com/resource/en/application_note/an5617-stm32h745755-and-stm32h747757-lines-interprocessor-communications-stmicroelectronics.pdf
Application Notes | https://www.st.com/resource/en/application_note/an4899-stm32-microcontroller-gpio-hardware-settings-and-lowpower-consumption-stmicroelectronics.pdf
Application Notes | https://www.st.com/resource/en/application_note/an5612-esd-protection-of-stm32-mcus-and-mpus-stmicroelectronics.pdf
Application Notes | https://www.st.com/resource/en/application_note/an5293-migration-guide-from-stm32f7-series-to-stmh74x75x-stm32h72x73x-and-stmh7a37bx-devices-stmicroelectronics.pdf
Application Notes | https://www.st.com/resource/en/application_note/an4991-how-to-wake-up-an-stm32-microcontroller-from-lowpower-mode-with-the-usart-or-the-lpuart-stmicroelectronics.pdf
Application Notes | https://www.st.com/resource/en/application_note/an4838-introduction-to-memory-protection-unit-management-on-stm32-mcus-stmicroelectronics.pdf
Application Notes | https://www.st.com/resource/en/application_note/an5927-i3c-protocol-used-in-the-stm32-bootloader-stmicroelectronics.pdf
Application Notes | https://www.st.com/resource/en/application_note/an5225-introduction-to- usb-typec-power-delivery-for-stm32-mcus-and-mpus-

| stmicroelectronics.pdf
Application Notes | https://www.st.com/resource/en/application_note/an5342--how-to-use-error-correction-code-ecc-management-for-internal-memories-protection-on-stm32-mcus-stmicroelectro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
Application Notes | https://www.st.com/resource/en/application_note/an4938-getting-started-with-stm32h74xig-and-stm32h75xig-mcu-hardware-development-stmicroelectronics.pdf
Application Notes | https://www.st.com/resource/en/application_note/an5537-how-to-use-adc-oversampling-techniques-to-improve-signaltonoise-ratio-on-stm32-mcus-stmicroelectronics.pdf
Application Notes | https://www.st.com/resource/en/application_note/an5036-guidelines-for-thermal-management-on-stm32-applications-stmicroelectronics.pdf
Application Notes | https://www.st.com/resource/en/application_note/an5405-how-to-use-fdcan-bootloader-protocol-on-stm32-mcus-stmicroelectronics.pdf
Application Notes | https://www.st.com/resource/en/application_note/an5690-how-to-use-vrefbuf-peripheral-on-stm32-mcus-and-mpus-stmicroelectronics.pdf
Application Notes | https://www.st.com/resource/en/application_note/an4230-introduction-to-random-number-generation-validation-using-the-nist-statistical-test-suite-for-stm32-mcus-and-m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
Application Notes | https://www.st.com/resource/en/application_note/an2867-guidelines-for-oscillator-design-on-stm8afals-and-stm32-mcusmpus-stmicroelectronics.pdf
Application Notes | https://www.st.com/resource/en/application_note/an4013-introduction-to-timers-for-stm32-mcus-stmicroelectronics.pdf
Application Notes | https://www.st.com/resource/en/application_note/an4277-how-to-use-pwm-shutdown-for-motor-control-and-digital-power-conversion-on-stm32-mcus-stmicroelectronics.pdf
Application Notes | https://www.st.com/resource/en/application_note/an4635-how-to-optimize-lpuart-power-consumption-on-stm32-mcus-stmicroelectronics.pdf
Application Notes | https://www.st.com/resource/en/application_note/an4759-introduction-to-using-the-hardware-realtime-clock-rtc-and-the-tamper-management-unit-tamp-with-stm32-mcus-stmi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

Application Notes | https://www.st.com/resource/en/application_note/an4861-introduction-to-lcdtft-display-controller-ltdc-on-stm32-mcus-stmicroelectronics.pdf
Application Notes | https://www.st.com/resource/en/application_note/an4908-getting-started-with-usart-automatic-baud-rater-detection-for-stm32-mcus-stmicroelectronics.pdf
Application Notes | https://www.st.com/resource/en/application_note/an4943-how-to-use-chromart-accelerator-to-refresh-an-lcdtft-display-on-stm32-mcus-stmicroelectronics.pdf
Application Notes | https://www.st.com/resource/en/application_note/an5156-introduction-to-security-for-stm32-mcus-stmicroelectronics.pdf
Application Notes | https://www.st.com/resource/en/application_note/an5200-getting-started-with-stm32h7-mcus-sdmmc-host-controller-stmicroelectronics.pdf
Application Notes | https://www.st.com/resource/en/application_note/an5224-introduction-to-dmamux-for-stm32-mcus-stmicroelectronics.pdf
Application Notes | https://www.st.com/resource/en/application_note/an5507-how-to-use-crc-to-check-the-integrity-of-the-internal-flash-memory-on-stm32h7-mcus-stmicroelectronics.pdf
Application Notes | https://www.st.com/resource/en/application_note/an5543-guidelines-for-enhanced-spi-communication-on-stm32-mcus-and-mpus-stmicroelectronics.pdf
Application Notes | https://www.st.com/resource/en/application_note/an5337-guidelines-for-estimating-stm32h7-mcus-lifetime-stmicroelectronics.pdf
Application Notes | https://www.st.com/resource/en/application_note/an4996-how-to-use-the-jpeg-codec-peripheral-on-stm32-mcus-stmicroelectronics.pdf
Application Notes | https://www.st.com/resource/en/application_note/an5348-introduction-to-fdcan-peripherals-for-stm32-mcus-stmicroelectronics.pdf
Application Notes | https://www.st.com/resource/en/application_note/cd00211314-how-to-optimize-the-adc-accuracy-in-the-stm32-mcus-stmicroelectronics.pdf
Application Notes | https://www.st.com/resource/en/application_note/an2639-soldering-recommendations-and-package-information-for-leadfree-ecopack2-mcus-and-mpus-stmicroelectronics.pdf
Application Notes | https://www.st.com/resource/en/application_note/an5020-introduction-to-digital-camera-interface-dcmi-for-stm32-mcus-stmicroelectronics.pdf

Application Notes | https://www.st.com/resource/en/application_note/an4566-how-to-extend-the-dac-performance-on-stm32-mcus-stmicroelectronics.pdf
Application Notes for related Tools & Software | https://www.st.com/resource/en/application_note/an4323-getting-started-with-stemwin-library-stmicroelectronics.pdf
Application Notes for related Tools & Software | https://www.st.com/resource/en/application_note/an4435-guidelines-for-obtaining-ulcsaiec-607301603351-class-b-certification-in-any-stm32-application-stmicroelectroni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
Application Notes for related Tools & Software | https://www.st.com/resource/en/application_note/an4657-stm32-inapplication-programming-iap-using-the-usart-stmicroelectronics.pdf
Application Notes for related Tools & Software | https://www.st.com/resource/en/application_note/an4841-digital-signal-processing-for-stm32-microcontrollers-using-cmsis-stmicroelectronics.pdf
Application Notes for related Tools & Software | https://www.st.com/resource/en/application_note/an4891-stm32h72x-stm32h73x-and-singlecore-stm32h74x75x-system-architecture-and-performance-stmicroelectronics.pdf
Application Notes for related Tools & Software | https://www.st.com/resource/en/application_note/an5001-stm32cube-expansion-package-for-stm32h7-series-mdma-stmicroelectronics.pdf
Application Notes for related Tools & Software | https://www.st.com/resource/en/application_note/an5014-stm32h7x3-smart-power-management-expansion-package-for-stm32cube-stmicroelectronics.pdf
Application Notes for related Tools & Software | https://www.st.com/resource/en/application_note/an5033-stm32cube-mcu-package-examples-for-stm32h7-series-stmicroelectronics.pdf
Application Notes for related Tools & Software | https://www.st.com/resource/en/application_note/an5056-integration-guide-for-the-xcubesbsfu-stm32cube-expansion-package-stmicroelectronics.pdf
Application Notes for related Tools & Software | https://www.st.com/resource/en/application_note/an5360-getting-started-with-projects-based-on-the-stm32mp1-series-in-stm32cubeide-stmicroelectronics.pdf

Application Notes
for related Tools

https://www.st.com/resource/en/application_note/an5361-getting-startedwith-projects-based-on-dualcore-stm32h7-microcontrollers-in-

& Software | stm32cubeide-stmicroelectronics.pdf
Application Notes for related Tools & Software | https://www.st.com/resource/en/application_note/an5394-getting-started-with-projects-based-on-the-stm32l5-series-in-stm32cubeide-stmicroelectronics.pdf
Application Notes for related Tools & Software | https://www.st.com/resource/en/application_note/an5418-how-to-build-a-simple-usbpd-sink-application-with-stm32cubemx-stmicroelectronics.pdf
Application Notes for related Tools & Software | https://www.st.com/resource/en/application_note/an5426-migrating-graphics-middleware-projects-from-stm32cubemx-540-to-stm32cubemx-550-stmicroelectronics.pdf
Application Notes for related Tools & Software | https://www.st.com/resource/en/application_note/an5564-getting-started-with-projects-based-on-dualcore-stm32wl-microcontrollers-in-stm32cubeide-stmicroelectronics.pd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
Application Notes for related Tools & Software | https://www.st.com/resource/en/application_note/an4865-lowpower-timer-lptim-applicative-use-cases-on-stm32-mcus-and-mpus-stmicroelectronics.pdf
Application Notes for related Tools & Software | https://www.st.com/resource/en/application_note/an5698-adapting-the-xcubestl-functional-safety-package-for-stm32-iec-61508-compliant-to-other-safety-standards-stmicr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
Application Notes for related Tools & Software | https://www.st.com/resource/en/application_note/an5731-stm32cubemx-and-stm32cubeide-threadsafe-solution-stmicroelectronics.pdf
Application Notes for related Tools & Software | https://www.st.com/resource/en/application_note/an5450-stm32h7a37b3-lines-and-stm32h7b0-value-line-smart-power-management-expansion-package-for-stm32cube-stmicroelec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
Application Notes for related Tools & Software | https://www.st.com/resource/en/application_note/an4502-stm32-smbuspmbus-expansion-package-for-stm32cube-stmicroelectronics.pdf
Application Notes for related Tools & Software | https://www.st.com/resource/en/application_note/an5952-how-to-use-cmake-in-stm32cubeide-stmicroelectronics.pdf
Application Notes for related Tools & Software | https://www.st.com/resource/en/application_note/an4635-how-to-optimize-lpuart-power-consumption-on-stm32-mcus-stmicroelectronics.pdf

Application Notes for related Tools & Software | https://www.st.com/resource/en/application_note/an5054-how-to-perform-secure-programming-using-stm32cubeprogrammer-stmicroelectronics.pdf
Application Notes for related Tools & Software | https://www.st.com/resource/en/application_note/an6088-how-to-use-mce-for-encryptiondecryption-on-stm32-mcus-stmicroelectronics.pdf
Application Notes for related Tools & Software | https://www.st.com/resource/en/application_note/an6179-how-to-integrate-the-stl-firmware-into-a-time-critical-user-application-stmicroelectronics.pdf
Application Notes for related Tools & Software | https://www.st.com/resource/en/application_note/an6127-getting-started-with-stm32h7rx7sx-mcus-in-stm32cubeide-stmicroelectronics.pdf
Design Notes & Tips | https://www.st.com/resource/en/design_tip/dt0117-microphone-array-beamforming-in-the-pcm-and-pdm-domain-stmicroelectronics.pdf
Errata Sheets | https://www.st.com/resource/en/errata_sheet/es0445-stm32h745xig-stm32h755xi-stm32h747xig-stm32h757xi-device-errata-stmicroelectronics.pdf
Datasheet | https://www.st.com/resource/en/datasheet/dm00600954.pdf
Programming Manuals | https://www.st.com/resource/en/programming_manual/pm0214-stm32-cortexm4-mcus-and-mpus-programming-manual-stmicroelectronics.pdf
Programming Manuals | https://www.st.com/resource/en/programming_manual/pm0253-stm32f7-series-and-stm32h7-series-cortexm7-processor-programming-manual-stmicroelectronics.pdf
Reference Manuals | https://www.st.com/resource/en/reference_manual/rm0399-stm32h745755-and-stm32h747757-advanced-armbased-32bit-mcus-stmicroelectronics.pdf
Technical Notes & Articles | https://www.st.com/resource/en/technical_note/tn1163-description-of-wlcsp-for-microcontrollers-and-recommendations-for-its-use-stmicroelectronics.pdf
Technical Notes & Articles | https://www.st.com/resource/en/technical_note/tn1204-tape-and-reel-shipping-media-for-stm32-microcontrollers-in-bga-packages-stmicroelectronics.pdf

Technical Notes
& Articles

https://www.st.com/resource/en/technical_note/tn1205-tape-and-reelshipping-media-for-stm8-and-stm32-microcontrollers-in-fpn-packages-

| stmicroelectronics.pdf
Technical Notes & Articles | https://www.st.com/resource/en/technical_note/tn1206-tape-and-reel-shipping-media-for-stm8-and-stm32-microcontrollers-in-qfp-packages-stmicroelectronics.pdf
Technical Notes & Articles | https://www.st.com/resource/en/technical_note/tn1207-tape-and-reel-shipping-media-for-stm8-and-stm32-microcontrollers-in-so-packages-stmicroelectronics.pdf
Technical Notes & Articles | https://www.st.com/resource/en/technical_note/tn1208-tape-and-reel-shipping-media-for-stm8-and-stm32-microcontrollers-in-tssop-and-ssop-packages-stmicroelectronics.p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
Technical Notes & Articles | https://www.st.com/resource/en/technical_note/tn1433-reference-device-marking-schematics-for-stm32-microcontrollers-and-microprocessors-stmicroelectronics.pdf
User Manuals | https://www.st.com/resource/en/user_manual/um2840-stm32h7-dualcore-series-safety-manual-stmicroelectronics.pdf
User Manuals | https://www.st.com/resource/en/user_manual/um2331-stm32h7-singlecore-series-safety-manual-stmicroelectronics.pdf
User Manuals | https://www.st.com/resource/en/user_manual/um3252-stm32h7-series-ulcsaiec-607301603351-selftest-library-user-guide-stmicroelectronics.pdf

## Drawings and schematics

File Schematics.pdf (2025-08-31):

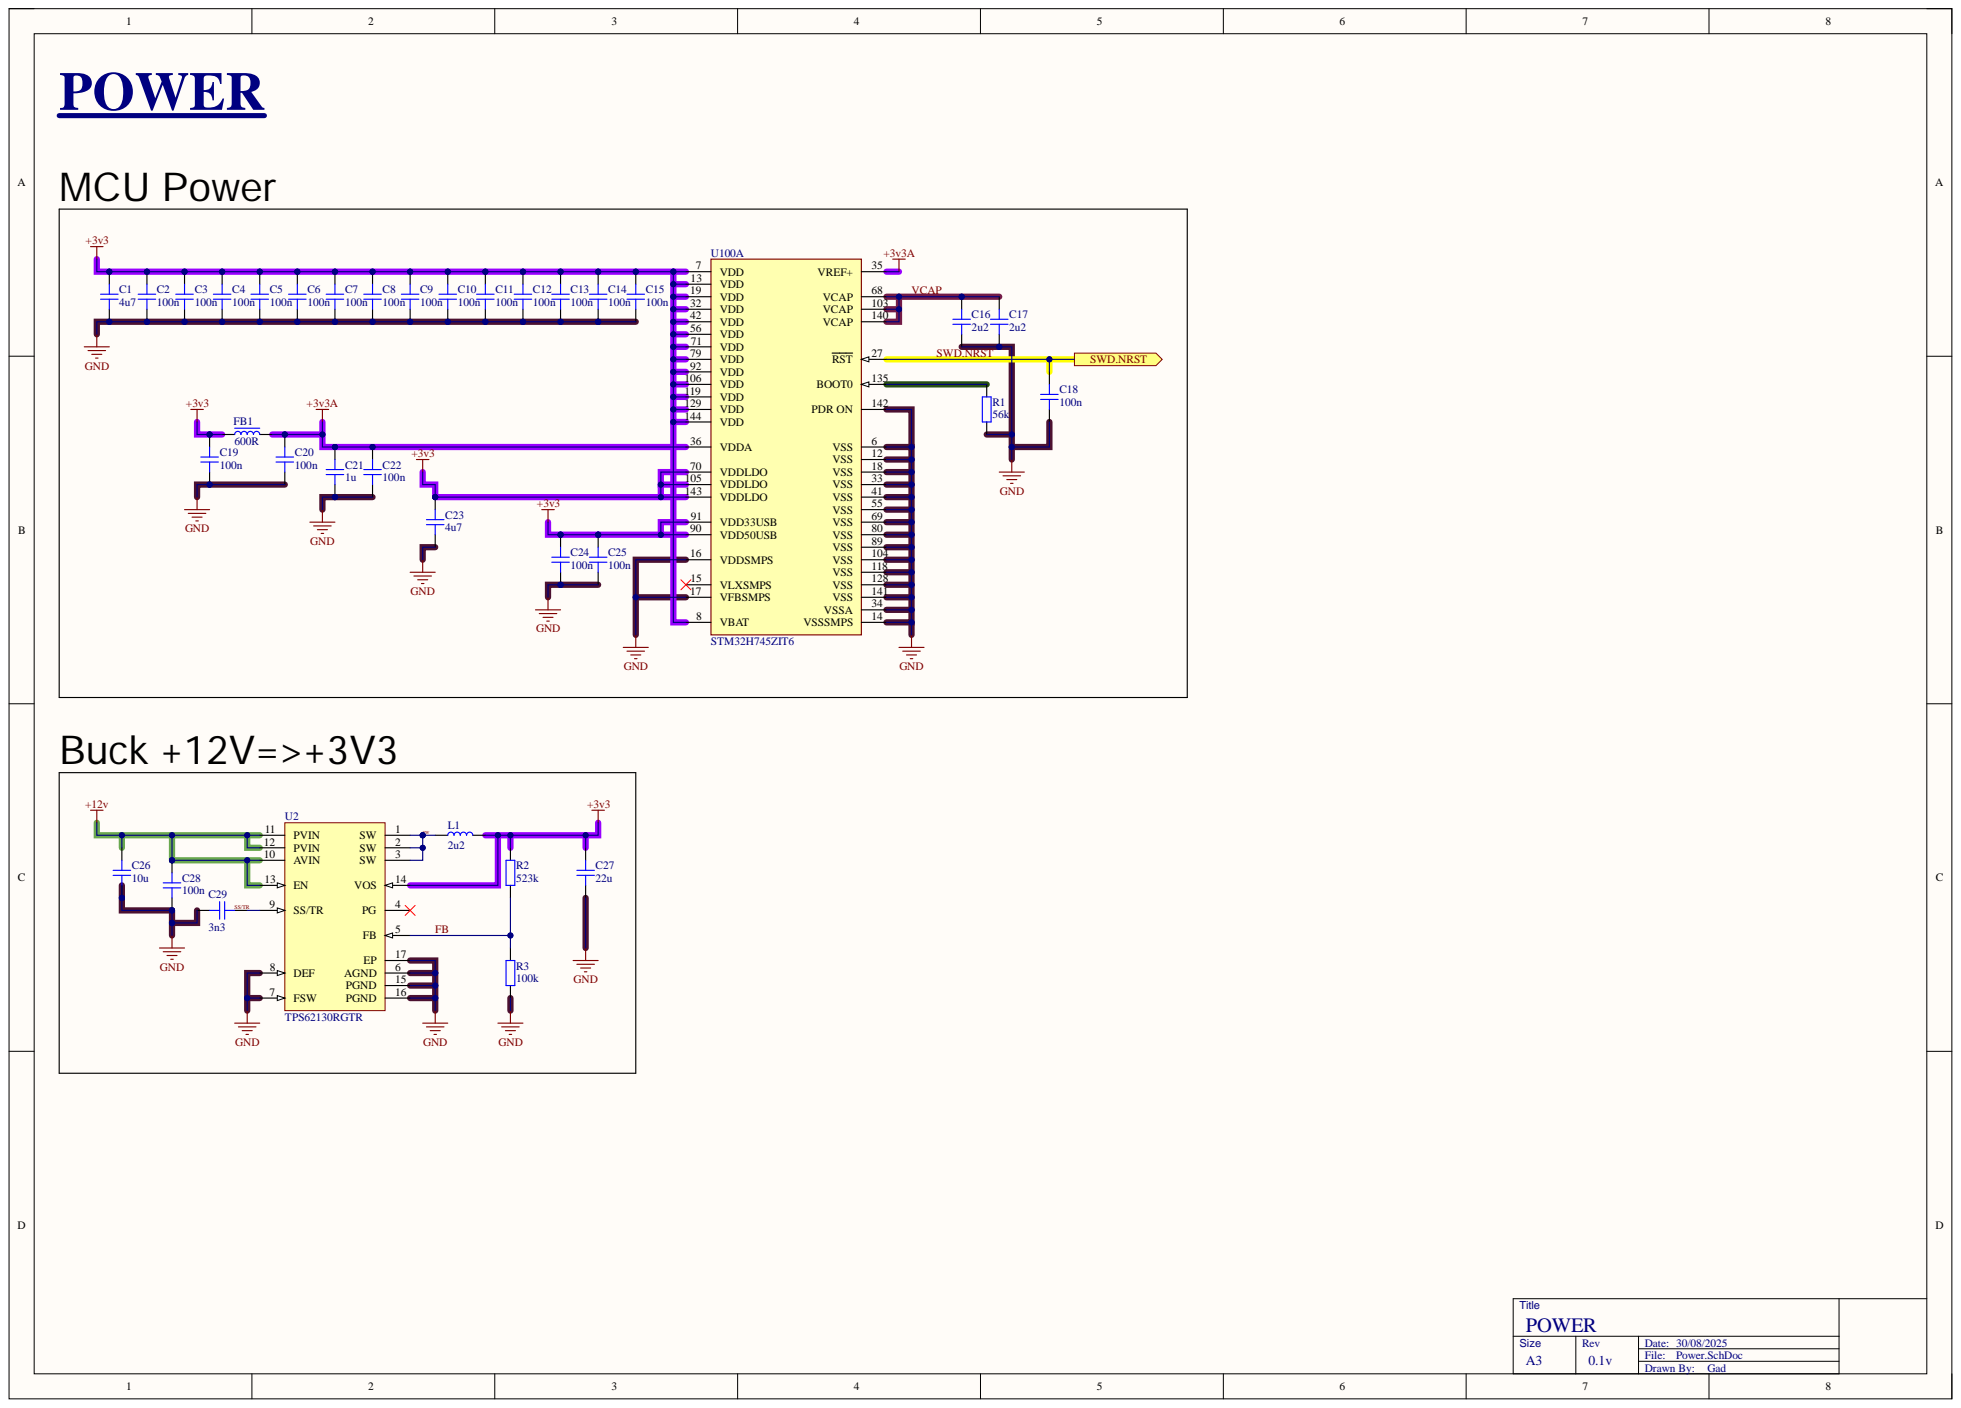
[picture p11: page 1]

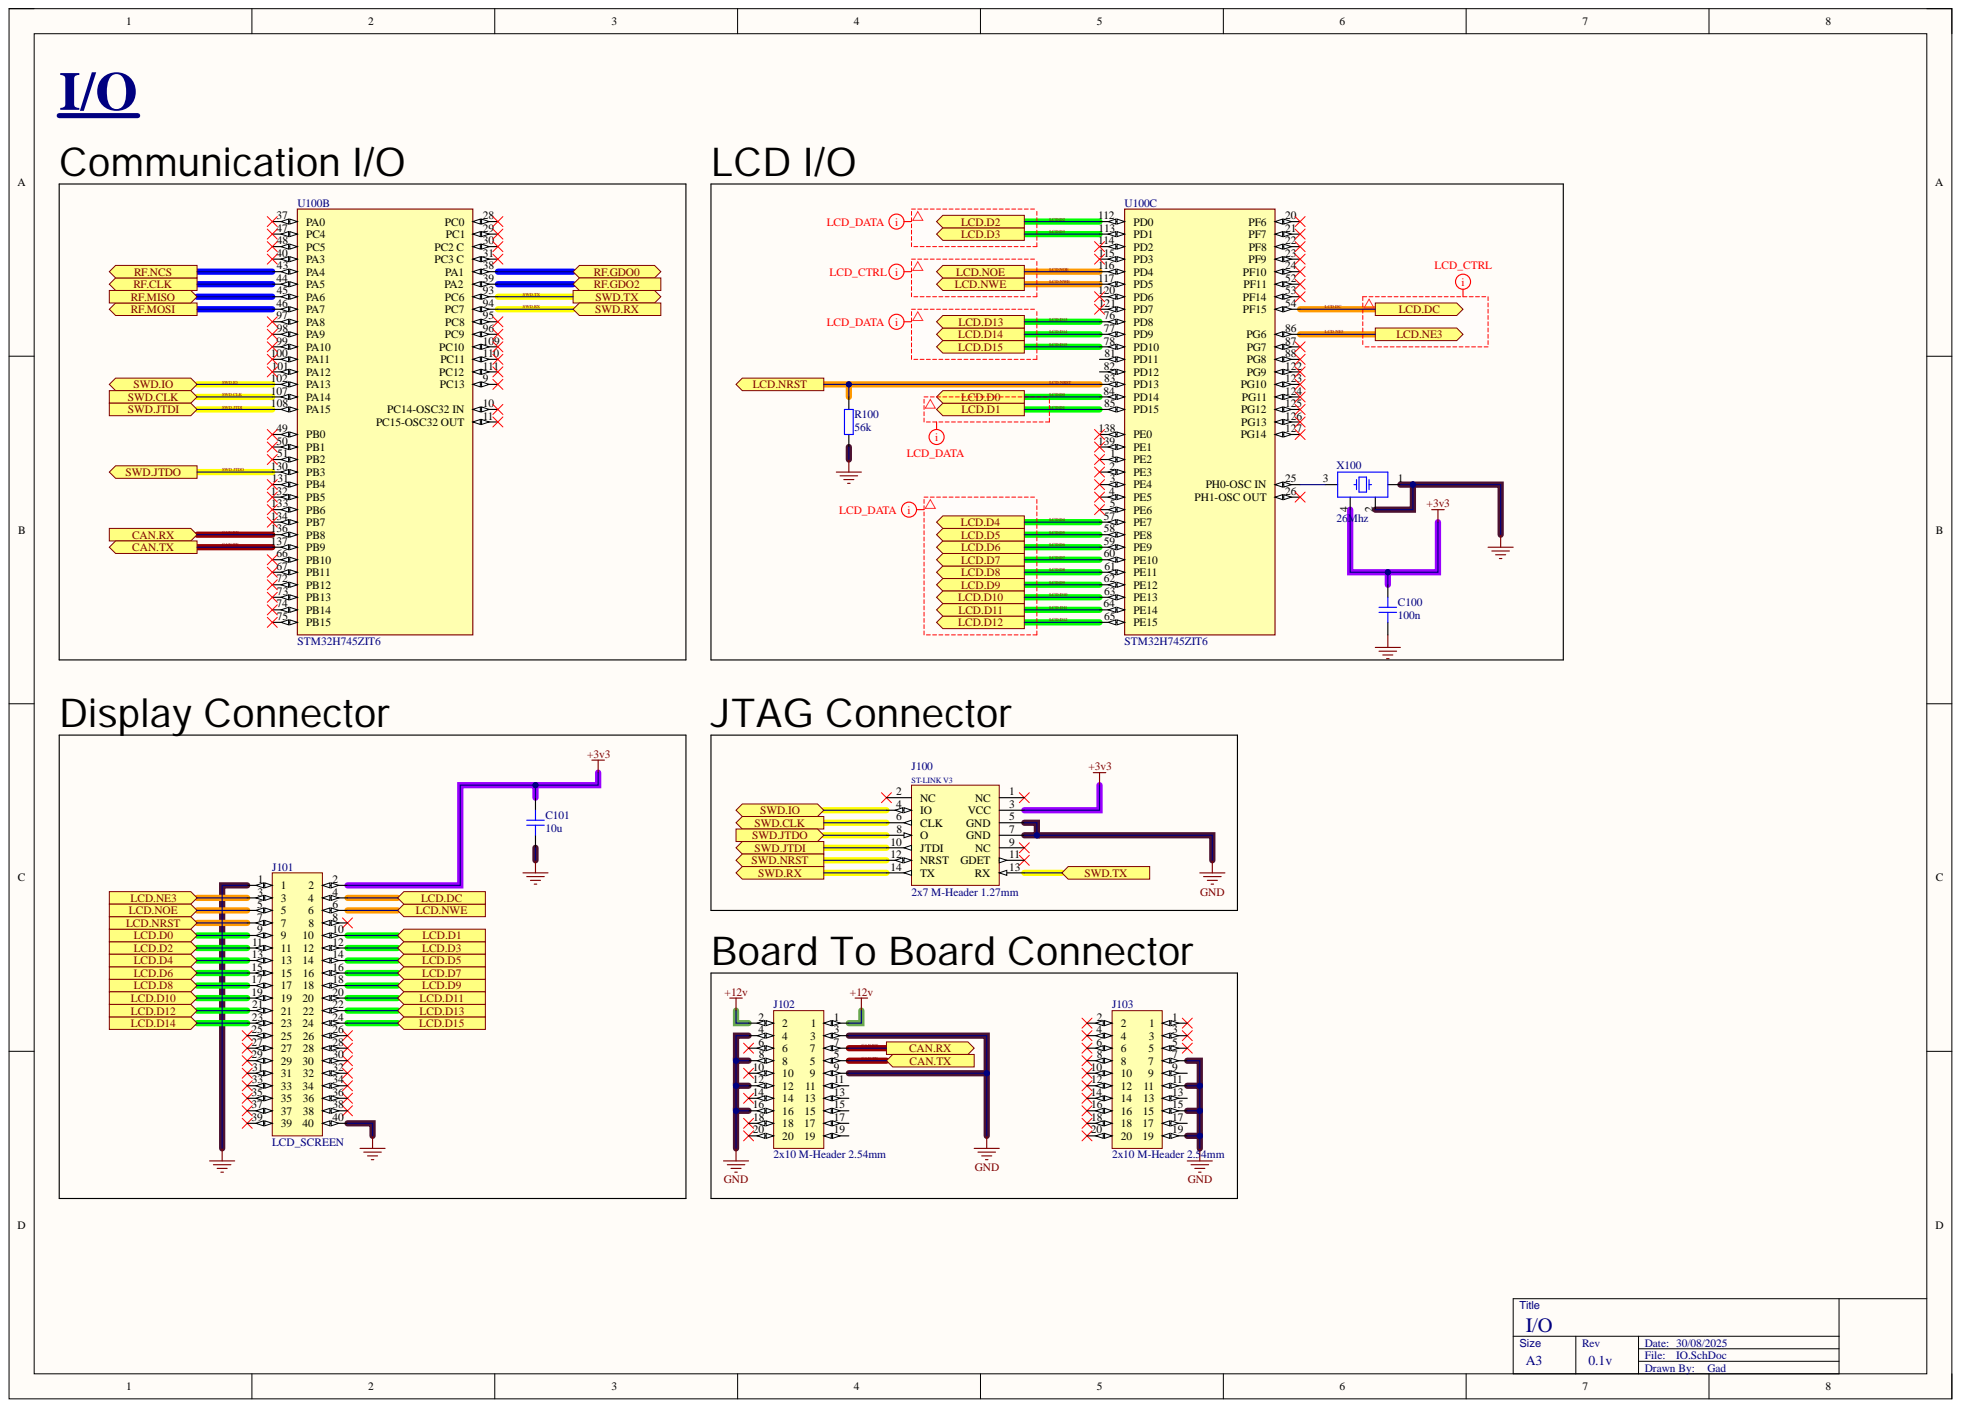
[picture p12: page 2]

LCD.DC

LCD.D1 | LCD.D1 | PD15 85

SWD.IO
SWD.CLK
SWD.JTDO
SWD.JTDI
SWD.NRST
Board To Board Connector

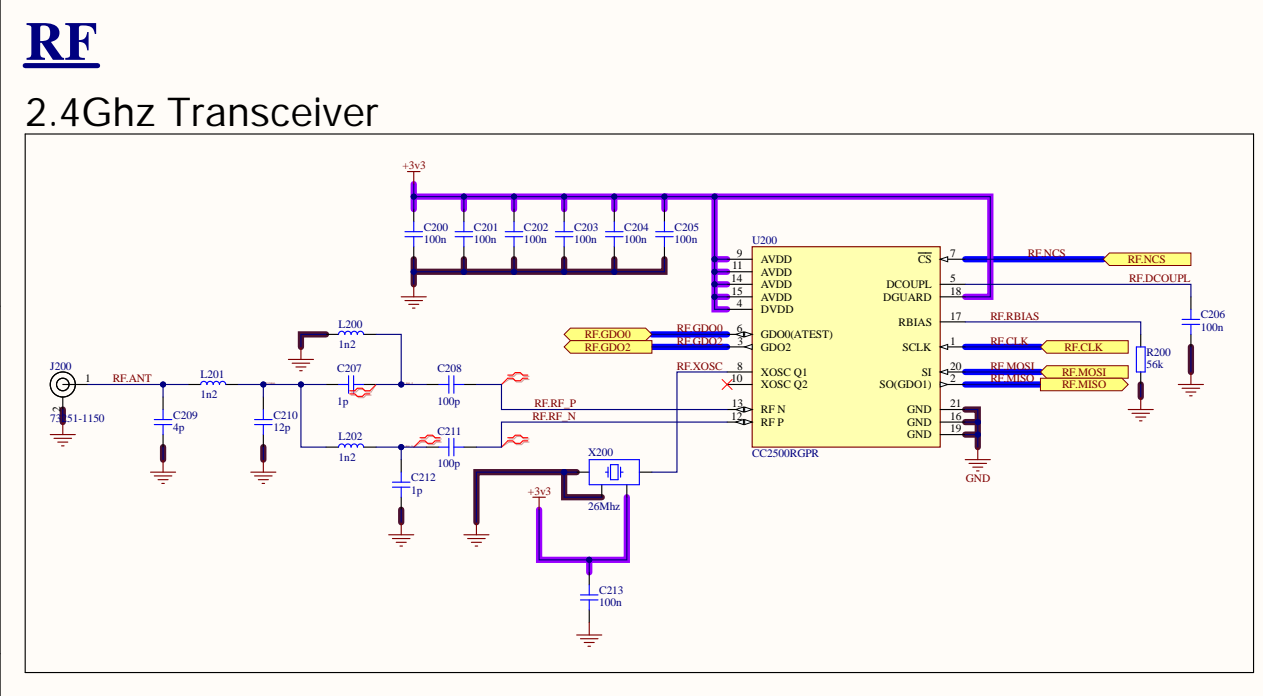
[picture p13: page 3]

XOSC Q2 10

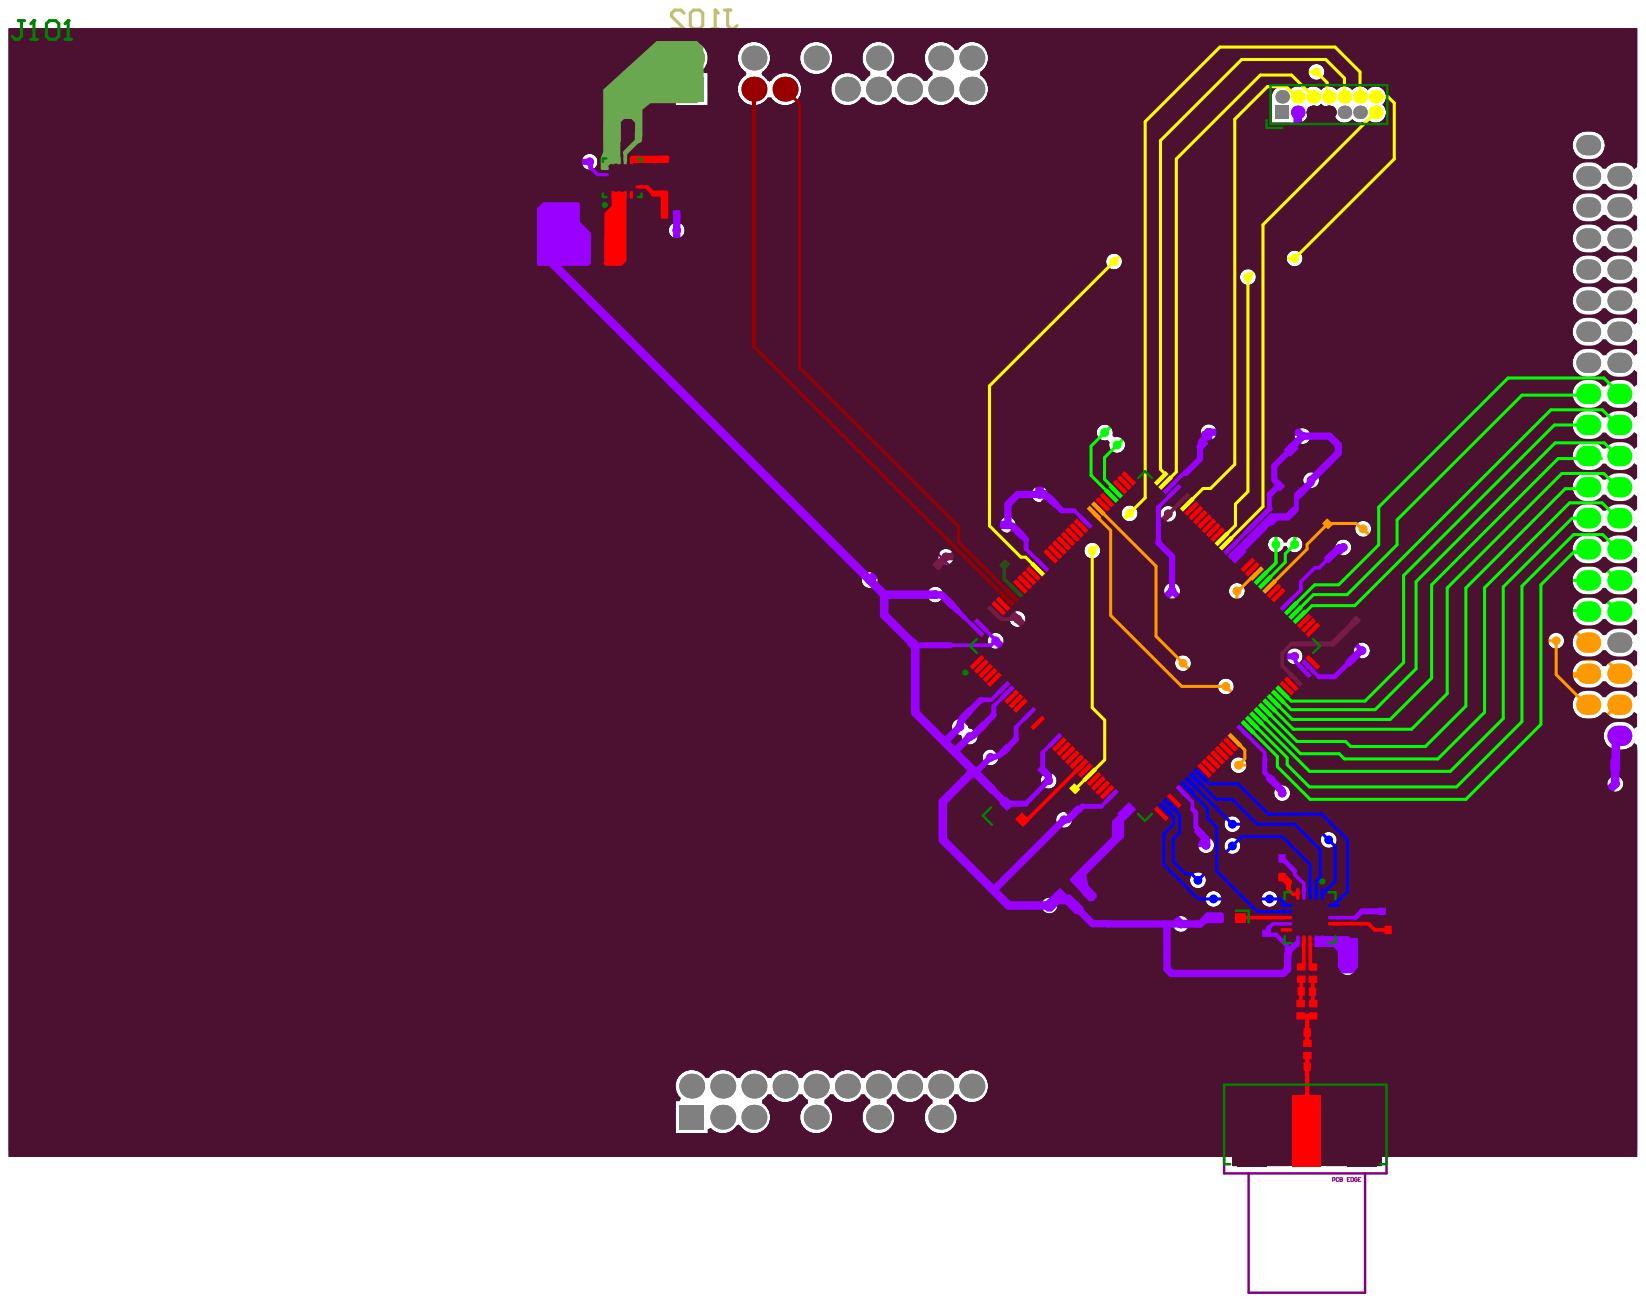
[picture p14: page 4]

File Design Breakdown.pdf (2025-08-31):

# Dash Concept RevA

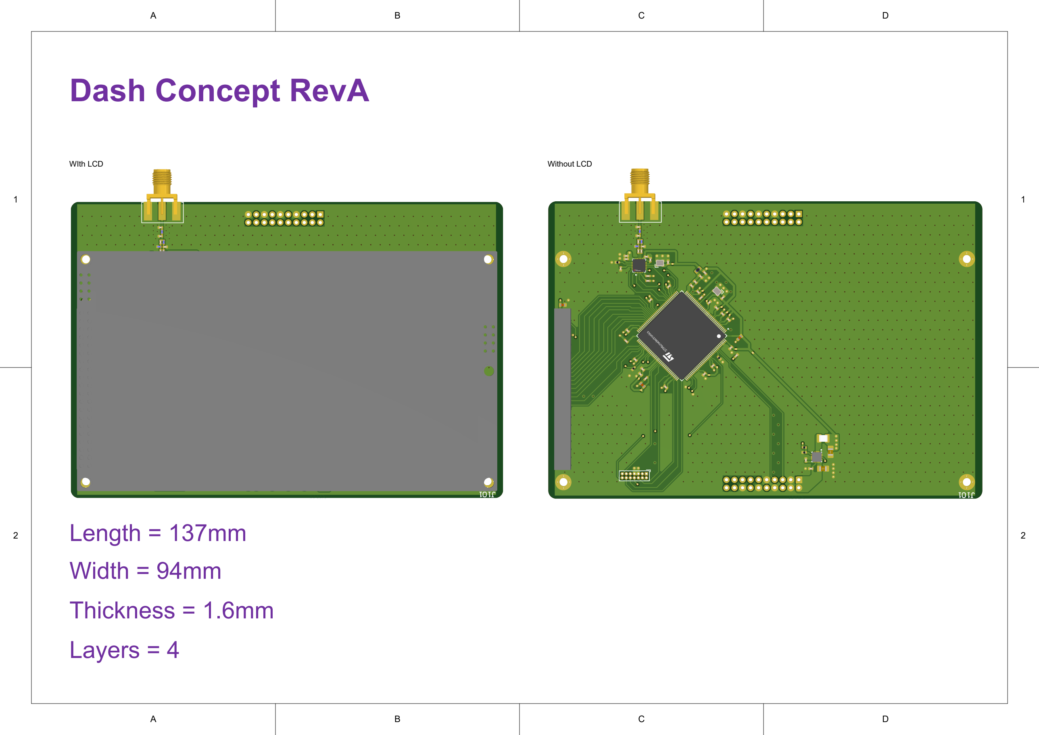
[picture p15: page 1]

A

B

C

D

1 | 1
2 | 2
WIth LCD | Without LCD

# Length = 137mm Width = 94mm Thickness = 1.6mm Layers = 4

# Dash Concept RevA Impedance & Stackup

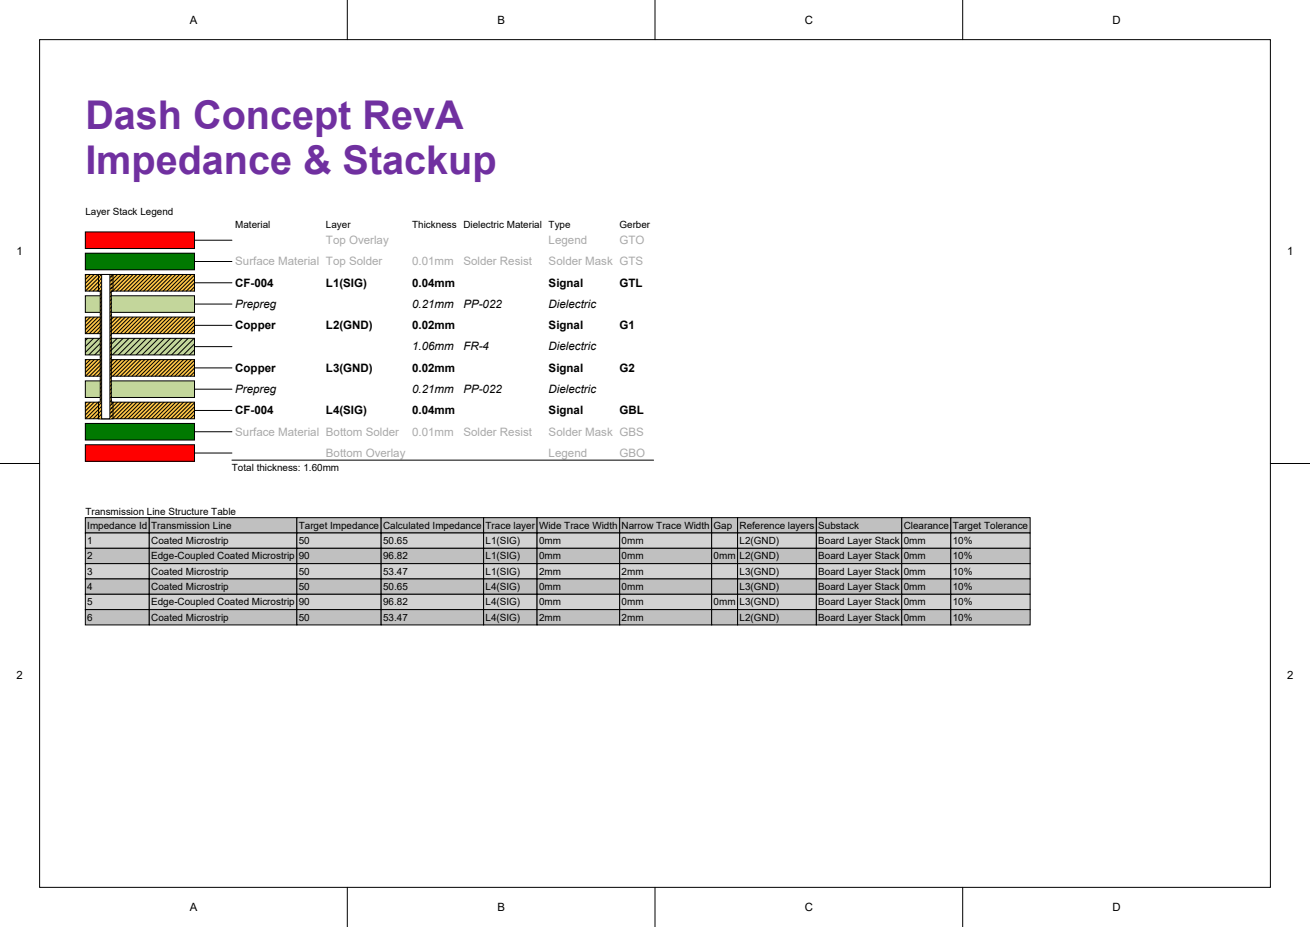
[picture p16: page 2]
Material; Layer; Thickness Dielectric Material Type; Gerber; Top Overlay; Legend; GTO; Surface Material Top Solder; 0.01mm Solder Resist; Solder Mask GTS; L1(SIG); Signal; GTL; Prepreg; Dielectric; Copper; L2(GND); L3(GND); L4(SIG); GBL; Surface Material Bottom Solder 0.01mm Solder Resist; Solder Mask GBS; Bottom Overlay; GBO; Total thickness: 1.60mm; Impedance Id 1 2 3 4 5 6; Target Impedance 50 90 50 50 90 50; Calculated Impedance 50.65 96.82 53.47 50.65 96.82 53.47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

Layer Stack Legend

Transmission Line
Coated Microstrip
Edge-Coupled Coated Microstrip

Substack
Board Layer Stack

# Dash Concept RevA Front & Back

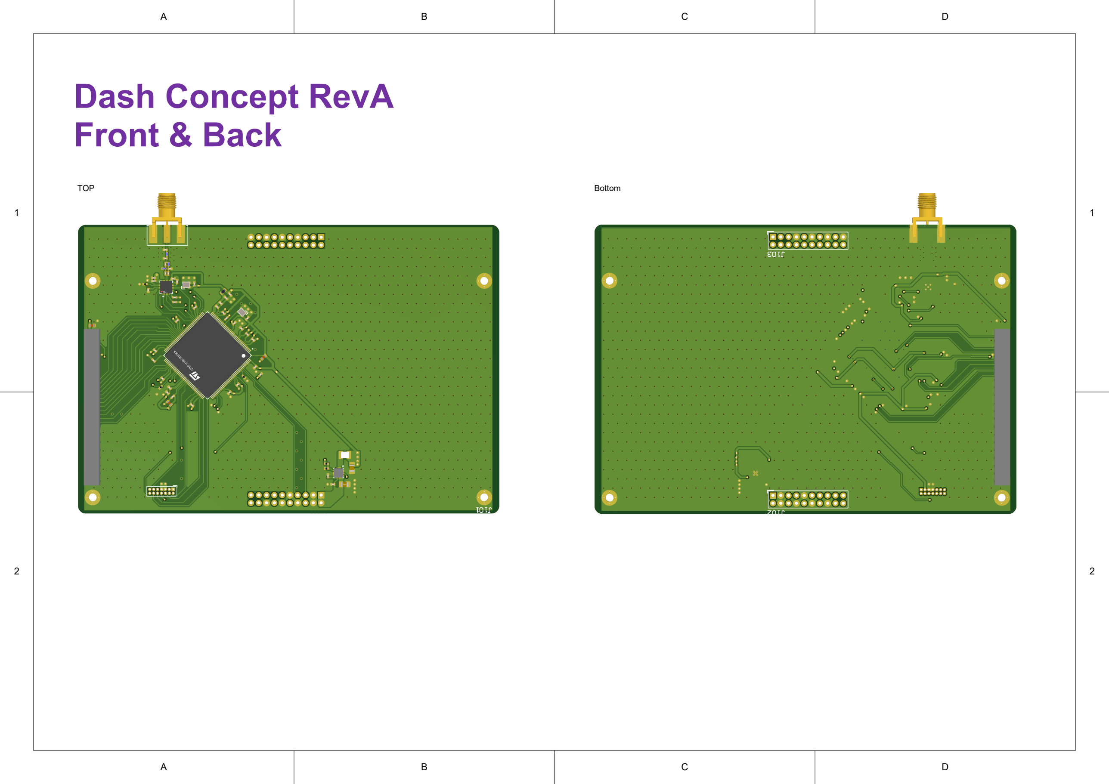
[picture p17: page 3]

1 | 1
2 | 2
TOP | Bottom

# Dash Concept RevA Layers

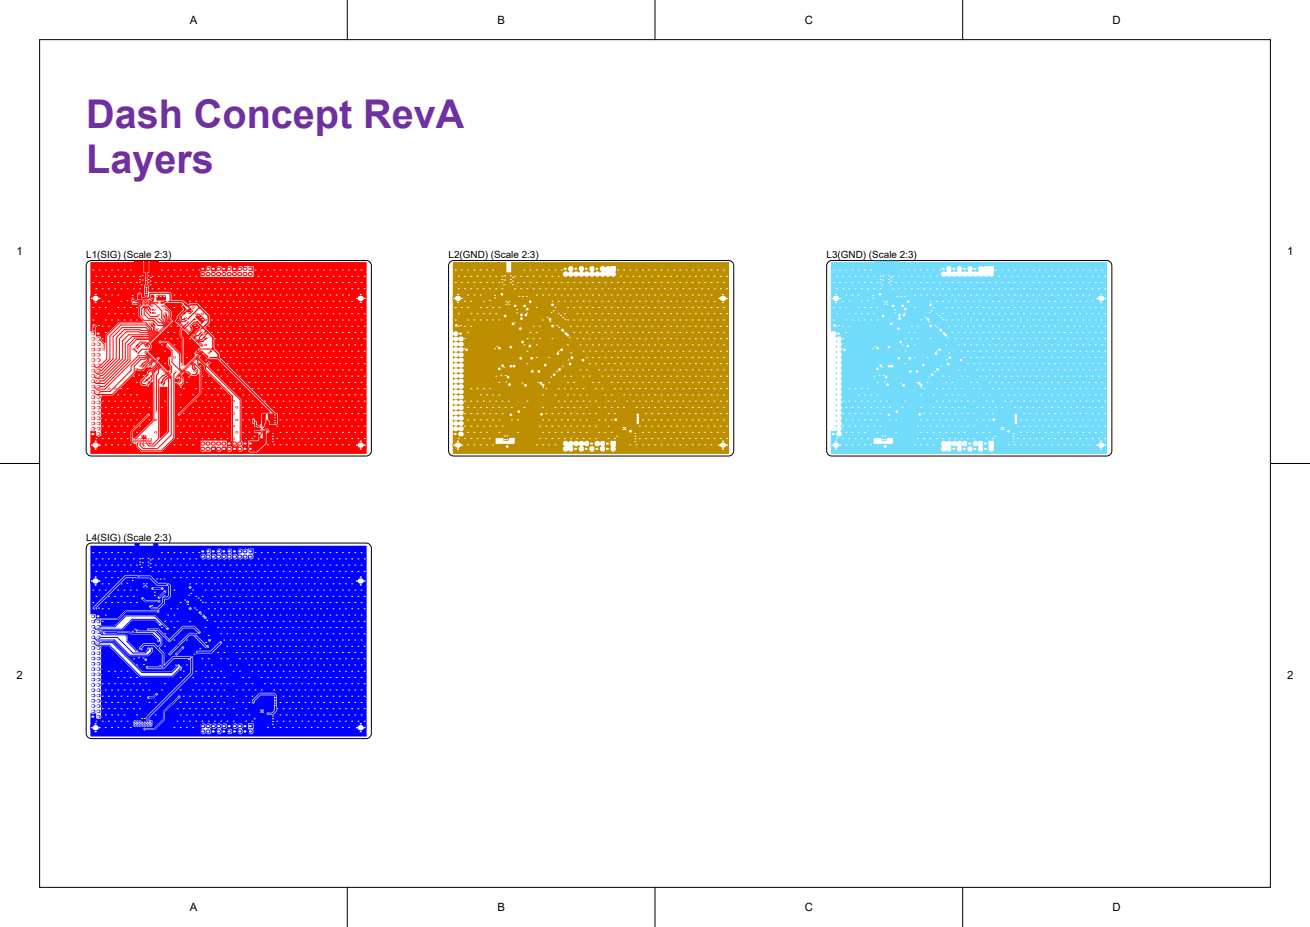
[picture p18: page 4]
L1(SIG) (Scale 2:3); L2(GND) (Scale 2:3); L3(GND) (Scale 2:3); L4(SIG) (Scale 2:3)

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
| Designator | Comment | Quantity 2
| C1, C23 | 4u7
Line # 123456789 | C2, C3, C4, C5, C6, C7, C8, C9, C10, C11, C12, C13, C14, C15, C18, C19, C20, C22, C24, C25, C28 | 100n
| C16, C17 | 2u2
| C21 | 1u
| C26 | 10u
| C27 | 22u
| C29 | 3n3
| C100, C200, C201, C202, C203, C204, C205, C213 | 100n
| C101 | 10u
10 | C206 | 100n | 2121111811211111112112111121112
11 | C207, C212 | 1p
12 | C208 | 100p
13 | C209 | 4p
14 | C210 | 12p
15 | C211 | 100p
16 | FB1 | 600R
17 | J100 | 2x7 M-Header 1.27mm
18 | J101 | LCD_SCREEN
19 | J102, J103 | 2x10 M-Header 2.54mm
20 | J200 | 73251-1150
21 | L1 | 2u2
22 | L200, L201 | 1n2
23 | L202 | 1n2
24 | R1 | 56k
25 | R2 | 523k
26 | R3 | 100k
27 | R100, R200 | 56k
28 | U2 | TPS62130RGTR
29 | U100 | STM32H745ZIT6
30 | U200 | CC2500RGPR
31 | X100, X200 | 26Mhz

Bill Of Materials

# Dash Concept RevA BOM

# Dash Concept RevA Drills

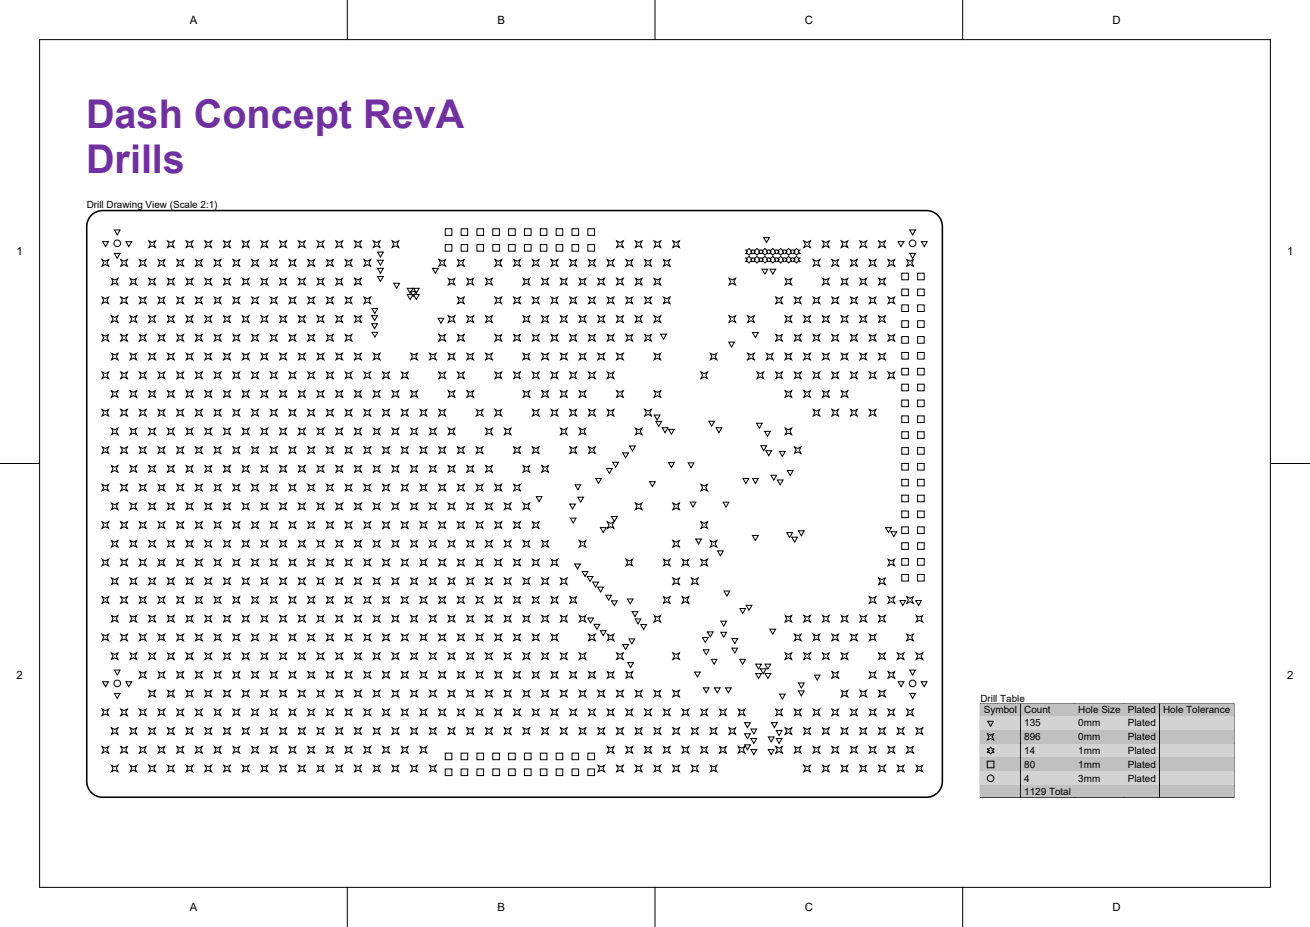
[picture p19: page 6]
Drill Table

Drill Drawing View (Scale 2:1)

Symbol | Count | Hole Size | Plated | Hole Tolerance

135 | 0mm | Plated
896 | 0mm | Plated
14 | 1mm | Plated
80 | 1mm | Plated
4 | 3mm | Plated
1129 Total
